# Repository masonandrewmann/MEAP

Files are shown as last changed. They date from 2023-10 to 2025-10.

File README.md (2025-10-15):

# Mason's ESP32 Audio Prototyping System

MEAP is a hardware and software environment for developing live computer music systems and rapidly prototyping digital electronic instruments.

MEAP's audio library is built as an expansion on top of [Mozzi](https://sensorium.github.io/Mozzi/), implementing extra features that take advantage of the computational power of the ESP32-S3 and improve/simplify the composer's experience.

[Documentation](https://masonmann.online/electronics/meap)

MEAP is used in [MPATE-GE 2047: Advanced Computer Music](https://masonmann.online/2047) at NYU

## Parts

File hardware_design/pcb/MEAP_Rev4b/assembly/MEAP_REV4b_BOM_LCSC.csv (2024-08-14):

Designator | Comment | Footprint | LCSC
U11 | TLV1117-50 | Package_TO_SOT_SMD:SOT-223-3_TabPin2 | ***
U9 | PAM8302AAD | Package_SO:MSOP-8_3x3mm_P0.65mm | C113367
U8 | SGTL5000XNLA3 | Package_DFN_QFN:QFN-20-1EP_3x3mm_P0.4mm_EP1.65x1.65mm | C2651833
U7 | TLV75733PDRV | Package_SON:WSON-6-1EP_2x2mm_P0.65mm_EP1x1.6mm | C2868428
U6 | AP7313-18A-7 | Package_TO_SOT_SMD:SOT-23 | C460372
U5 | MCP6002-xSN | Package_SO:SOIC-8_3.9x4.9mm_P1.27mm | C7377
U3 | ESP32-S3-WROOM-1 | PCM_Espressif:ESP32-S3-WROOM-1U | C3013946
U1 | 4051 | Package_SO:SOIC-16_3.9x9.9mm_P1.27mm | C21379
R26,R27 | 1k | Resistor_SMD:R_0603_1608Metric_Pad0.98x0.95mm_HandSolder | C21190
R25,R29,R30 | 100 | Resistor_SMD:R_0603_1608Metric_Pad0.98x0.95mm_HandSolder | C22775
R21,R23,R24 | 2k2 | Resistor_SMD:R_0603_1608Metric_Pad0.98x0.95mm_HandSolder | C4190
R10,R15 | 220 | Resistor_SMD:R_0603_1608Metric_Pad0.98x0.95mm_HandSolder | C22962
R5,R17,R18,R19,R20,R22,R28 | 10k | Resistor_SMD:R_0603_1608Metric_Pad0.98x0.95mm_HandSolder | C25804
R3,R6,R7,R9,R11,R12,R13,R14 | 100k | Resistor_SMD:R_0603_1608Metric_Pad0.98x0.95mm_HandSolder | C25803
R2,R8 | 47 | Resistor_SMD:R_0603_1608Metric_Pad0.98x0.95mm_HandSolder | C23182
R1,R4 | 330 | Resistor_SMD:R_0603_1608Metric_Pad0.98x0.95mm_HandSolder | C23138
Q1 | DMG2301L | Package_TO_SOT_SMD:SOT-23 | C102619
FB3,FB4 | 120 | Inductor_SMD:L_0603_1608Metric | C2941525
FB2 | 600 | Inductor_SMD:L_0603_1608Metric | C2982094
FB1 | 120 | Inductor_SMD:L_0603_1608Metric | C2941525
D3 | 1N4148 | Diode_SMD:D_SOD-323 | C2128
C25,C27 | 220p | Capacitor_SMD:C_0603_1608Metric_Pad1.08x0.95mm_HandSolder | C1603
C22 | 10u | Capacitor_SMD:C_0603_1608Metric_Pad1.08x0.95mm_HandSolder | C99231
C20 | 22u | Capacitor_SMD:C_1210_3225Metric | C342660
C16 | 0.15uF | Capacitor_SMD:C_0603_1608Metric_Pad1.08x0.95mm_HandSolder | C501839
C15 | 220n | Capacitor_SMD:C_0603_1608Metric_Pad1.08x0.95mm_HandSolder | C335532
C9,C11,C13,C14,C17,C19,C23,C24 | 2u2 | Capacitor_SMD:C_0603_1608Metric_Pad1.08x0.95mm_HandSolder | C914769
C2,C3,C4,C5,C6,C7,C8,C10,C12,C21 | 100n | Capacitor_SMD:C_0603_1608Metric_Pad1.08x0.95mm_HandSolder | C497032
C1,C18,C26,C30 | 1u | Capacitor_SMD:C_0603_1608Metric_Pad1.08x0.95mm_HandSolder | C696843
J22 | USB_B_Micro | Connector_USB:USB_Micro-B_Molex-105017-0001 | C136000

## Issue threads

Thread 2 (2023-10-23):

FTDI Header

masonandrewmann, 2023-10-23:
FTDI Header is very loose. At very least it needs strain relief but another kind of header might be better, or just uncut 6-pin headers. For now hot glue as stain relief seems to be the best option.

Closed 2023-10-30.

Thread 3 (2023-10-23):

Volume knob

masonandrewmann, 2023-10-23:
Volume knobs are very susceptible to being bent. They seem to become very noisy when this occurs. Maybe use a different kind of knob in the future.

masonandrewmann, 2023-10-23:
Volume knob also doesn't control line output, need to redesign the circuit for this. It would maybe also be nice to have a switched jack

Closed 2023-10-30.

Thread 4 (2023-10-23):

Control Knobs

masonandrewmann, 2023-10-23:
Control knobs get bent in backpacks. Would love to mount them on the box itself.

Closed 2023-10-30.

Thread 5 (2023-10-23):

Layout

masonandrewmann, 2023-10-23:
Several things get in the way of each other on the board.
When touch breakout is plugged in, the cable gets in the way of volume knob and programming buttons

Closed 2023-10-30.

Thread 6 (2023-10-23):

Kludges

masonandrewmann, 2023-10-23:
IO 19 is currently MISO for sd card SPI bus (pin 31 on kicad footprint)

IO 35 is currently PT_DIN for PT8211 (pin 7 on kicad footprint)

^^need to swap these

Volume Knob is backwards

SD card pins should be removed.

Closed 2024-08-14.

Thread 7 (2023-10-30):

rev3 hardware planning list

masonandrewmann, 2023-10-30:
midi output
CV output
Clock in/out
capacitive touch on i2c breakout with interrupts?

When touch breakout is plugged in, the cable gets in the way of volume knob and programming buttons
Spacing on program buttons is awkward, want to find a way to have FTDI programmer place ESP32 into PGM mode
FTDI header is flexible. Hot glue is a quick fix but would love a better connector.
Would love to avoid FTDI programming altogether, look into how arduino does their programming chip

How useful are the DIP switches?

Control knobs bend, maybe mount them on enclosure

Volume knob is easily damaged. Either use a non-trim pot or mount it somewhere else

Volume knob doesn't control headphone output. Place it before line out amp. Maybe also add switched jack

Stereo output? Maybe use a stereo 3.5mm as output instead of quarter inch?

Protection over speaker? (speaker grill cloth)

Maybe place pots on second mux and always use it (frees up a pin)

masonandrewmann, 2023-11-17:
FOR PROGRAMMING:
 Option 1: ESP32-S3 seems to have usb input pins
 Option 2: Use normal ESP32-WROOM with USB-UART chip (CP2102N)

Closed 2024-08-14.

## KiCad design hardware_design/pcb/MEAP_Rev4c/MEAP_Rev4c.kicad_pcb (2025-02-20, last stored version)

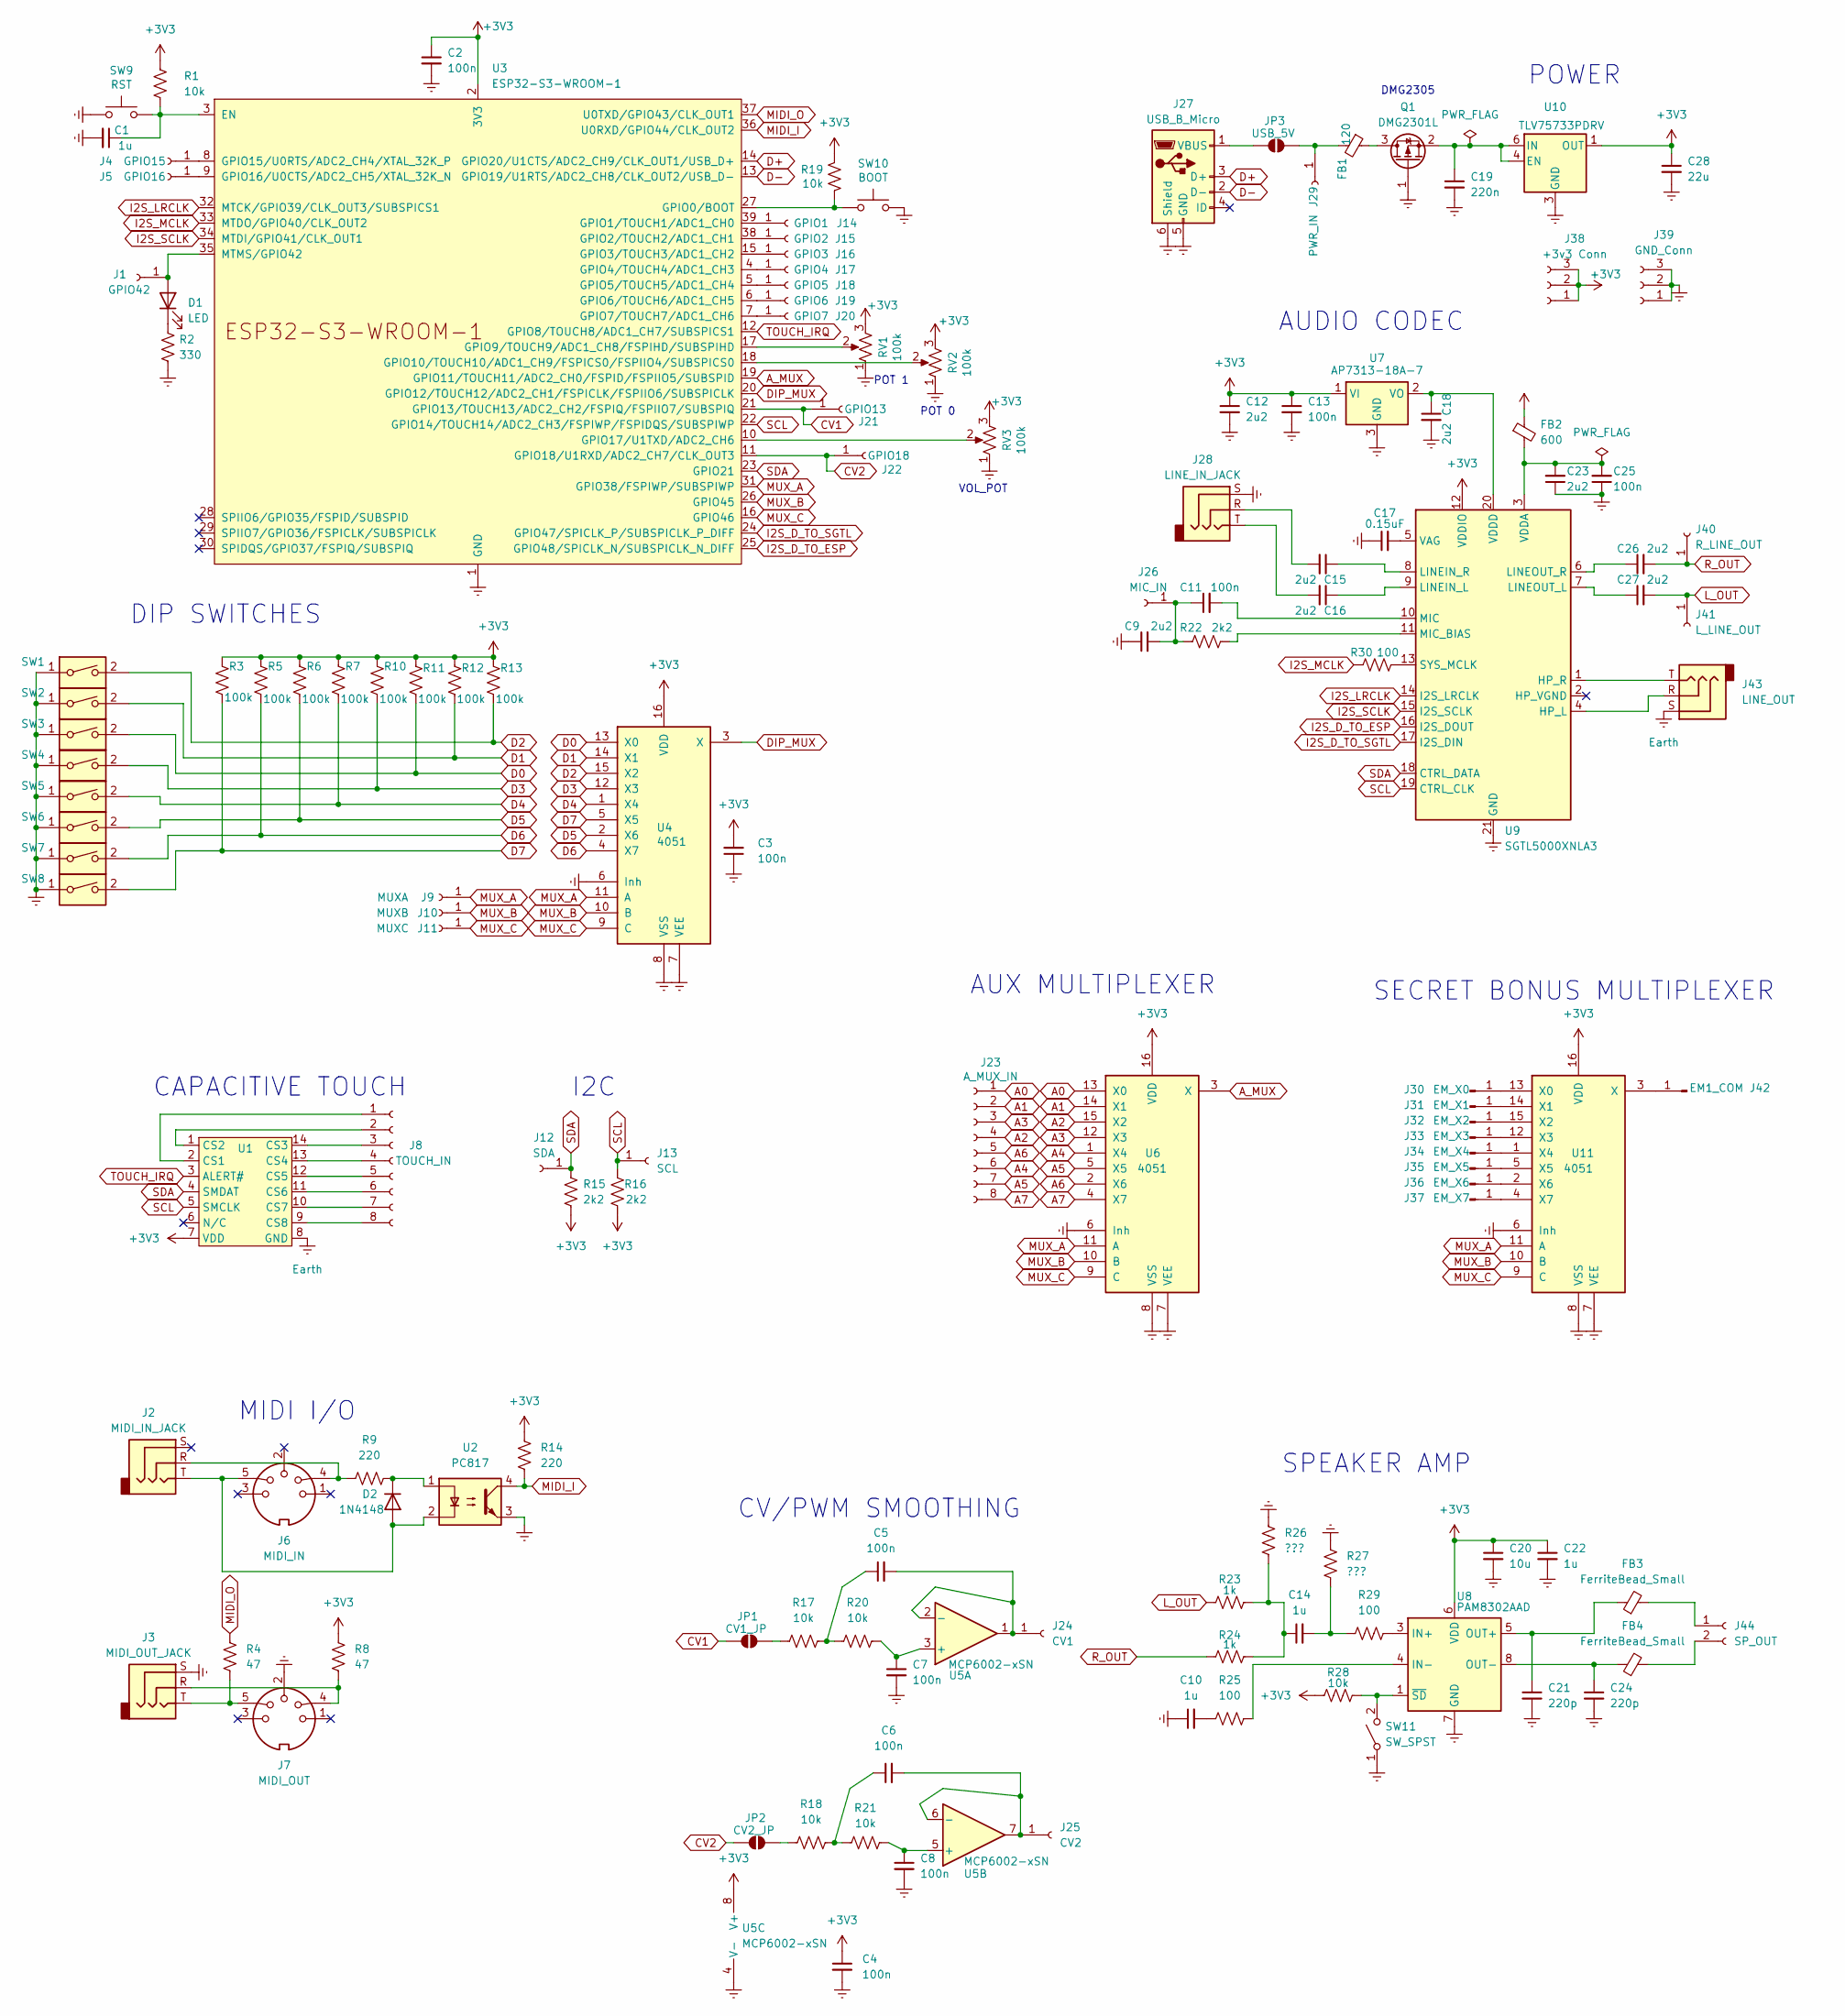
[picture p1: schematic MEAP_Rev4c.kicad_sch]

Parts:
C1, C10, C14, C22: 1u; C_0603_1608Metric_Pad1.08x0.95mm_HandSolder
C2, C3, C4, C5, C6, C7, C8, C11, C13, C25: 100n; C_0603_1608Metric_Pad1.08x0.95mm_HandSolder
C9, C12, C15, C16, C18, C23, C26, C27: 2u2; C_0603_1608Metric_Pad1.08x0.95mm_HandSolder
C17: 0.15uF; C_0603_1608Metric_Pad1.08x0.95mm_HandSolder
C19: 220n; C_0603_1608Metric_Pad1.08x0.95mm_HandSolder
C20: 10u; C_0603_1608Metric_Pad1.08x0.95mm_HandSolder
C21, C24: 220p; C_0603_1608Metric_Pad1.08x0.95mm_HandSolder
C28: 22u; C_1210_3225Metric
D1: LED; L_0805_2012Metric_Pad1.05x1.20mm_HandSolder
D2: 1N4148; D_SOD-323
FB1: 120; L_0603_1608Metric
FB2: 600; L_0603_1608Metric
FB3, FB4: FerriteBead_Small; L_0603_1608Metric
J1: GPIO42; Pin_D1.0mm_L10.0mm
J2: MIDI_IN_JACK; Jack_3.5mm_CUI_SJ1-3535NG_Horizontal_NO_FRONT
J3: MIDI_OUT_JACK; Jack_3.5mm_CUI_SJ1-3535NG_Horizontal_NO_FRONT
J4: GPIO15; Pin_D1.0mm_L10.0mm
J5: GPIO16; Pin_D1.0mm_L10.0mm
J6: MIDI_IN
J7: MIDI_OUT
J8: TOUCH_IN; PinHeader_2x04_P2.54mm_Vertical
J9: MUXA; Pin_D1.0mm_L10.0mm
J10: MUXB; Pin_D1.0mm_L10.0mm
J11: MUXC; Pin_D1.0mm_L10.0mm
J12: SDA; Pin_D1.0mm_L10.0mm
J13: SCL; Pin_D1.0mm_L10.0mm
J14: GPIO1; Pin_D1.0mm_L10.0mm
J15: GPIO2; Pin_D1.0mm_L10.0mm
J16: GPIO3; Pin_D1.0mm_L10.0mm
J17: GPIO4; Pin_D1.0mm_L10.0mm
J18: GPIO5; Pin_D1.0mm_L10.0mm
J19: GPIO6; Pin_D1.0mm_L10.0mm
J20: GPIO7; Pin_D1.0mm_L10.0mm
J21: GPIO13; Pin_D1.0mm_L10.0mm
J22: GPIO18; Pin_D1.0mm_L10.0mm
J23: A_MUX_IN; PinHeader_2x04_P2.54mm_Vertical
J24: CV1; Pin_D1.0mm_L10.0mm
J25: CV2; Pin_D1.0mm_L10.0mm
J26: MIC_IN; Pin_D1.0mm_L10.0mm
J27: USB_B_Micro; USB_Micro-B_Molex-105017-0001
J28: LINE_IN_JACK; Jack_3.5mm_CUI_SJ1-3535NG_Horizontal_NO_FRONT
J29: PWR_IN; Pin_D1.0mm_L10.0mm
J30: EM_X0; SolderWirePad_1x01_SMD_1x2mm
J31: EM_X1; SolderWirePad_1x01_SMD_1x2mm
J32: EM_X2; SolderWirePad_1x01_SMD_1x2mm
J33: EM_X3; SolderWirePad_1x01_SMD_1x2mm
J34: EM_X4; SolderWirePad_1x01_SMD_1x2mm
J35: EM_X5; SolderWirePad_1x01_SMD_1x2mm
J36: EM_X6; SolderWirePad_1x01_SMD_1x2mm
J37: EM_X7; SolderWirePad_1x01_SMD_1x2mm
J38: +3v3 Conn; PinHeader_1x03_P2.54mm_Vertical
J39: GND_Conn; PinHeader_1x03_P2.54mm_Vertical
J40: R_LINE_OUT; Pin_D1.0mm_L10.0mm
J41: L_LINE_OUT; Pin_D1.0mm_L10.0mm
J42: EM1_COM; SolderWirePad_1x01_SMD_1x2mm
J43: LINE_OUT; Jack_3.5mm_CUI_SJ1-3535NG_Horizontal_NO_FRONT
J44: SP_OUT; PinHeader_1x02_P2.54mm_Vertical
JP1: CV1_JP; SolderJumper-2_P1.3mm_Open_Pad1.0x1.5mm
JP2: CV2_JP; SolderJumper-2_P1.3mm_Open_Pad1.0x1.5mm
JP3: USB_5V; SolderJumper-2_P1.3mm_Open_Pad1.0x1.5mm
Q1: DMG2301L; SOT-23
R1, R17, R18, R19, R20, R21, R28: 10k; R_0603_1608Metric_Pad0.98x0.95mm_HandSolder
R2: 330; R_0603_1608Metric_Pad0.98x0.95mm_HandSolder
R3, R5, R6, R7, R10, R11, R12, R13: 100k; R_0603_1608Metric_Pad0.98x0.95mm_HandSolder
R4, R8: 47; R_0603_1608Metric_Pad0.98x0.95mm_HandSolder
R9, R14: 220; R_0603_1608Metric_Pad0.98x0.95mm_HandSolder
R15, R16, R22: 2k2; R_0603_1608Metric_Pad0.98x0.95mm_HandSolder
R23, R24: 1k; R_0603_1608Metric_Pad0.98x0.95mm_HandSolder
R25, R29, R30: 100; R_0603_1608Metric_Pad0.98x0.95mm_HandSolder
R26, R27: ???; R_0603_1608Metric_Pad0.98x0.95mm_HandSolder
RV1, RV2, RV3: 100k; PinHeader_1x03_P2.54mm_Vertical
SW1, SW2, SW3, SW4, SW5, SW6, SW7, SW8: SW_DIP_x01; SINGLE_DIP_SWITCH
SW9: RST; SW_Tactile_SPST_NO_Straight_CK_PTS636Sx25SMTRLFS
SW10: BOOT; SW_Tactile_SPST_NO_Straight_CK_PTS636Sx25SMTRLFS
SW11: SW_SPST; SW_Slide_SPDT_Straight_CK_OS102011MS2Q
U1: SOIC-14_3.9x8.7mm_P1.27mm
U2: PC817; DIP-4_W7.62mm
U3: ESP32-S3-WROOM-1; ESP32-S3-WROOM-1U
U4, U6, U11: 4051; SOIC-16_3.9x9.9mm_P1.27mm
U5: MCP6002-xSN; SOIC-8_3.9x4.9mm_P1.27mm
U7: AP7313-18A-7; SOT-23
U8: PAM8302AAD; MSOP-8_3x3mm_P0.65mm
U9: SGTL5000XNLA3; QFN-20-1EP_3x3mm_P0.4mm_EP1.65x1.65mm
U10: TLV75733PDRV; WSON-6-1EP_2x2mm_P0.65mm_EP1x1.6mm

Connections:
+3V3: C2.1, C3.2, C4.1, C12.1, C13.1, C20.1, C22.1, C28.1, FB2.1, J38.1, J38.2, J38.3, R1.1, R3.1, R5.1, R6.1, R7.1, R8.1, R10.1, R11.1, R12.1, R13.1, R14.1, R15.2, R16.2, R19.1, R28.1, RV1.3, RV2.3, RV3.3, U1.7 (VDD), U3.2 (3V3), U4.16 (VDD), U5.8 (V+), U6.16 (VDD), U7.1 (VI), U8.6 (VDD), U9.12 (VDDIO), U10.1 (OUT), U11.16 (VDD)
A0: J23.1, U6.13 (X0)
A1: J23.2, U6.14 (X1)
A2: J23.4, U6.15 (X2)
A3: J23.3, U6.12 (X3)
A4: J23.6, U6.1 (X4)
A5: J23.7, U6.5 (X5)
A6: J23.5, U6.2 (X6)
A7: J23.8, U6.4 (X7)
A_MUX: U3.19 (GPIO11/TOUCH11/ADC2_CH0/FSPID/FSPIIO5/S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), U6.3 (X)
CV1: J21.1, JP1.2 (B), U3.21 (GPIO13/TOUCH13/ADC2_CH2/FSPIQ/FSPIIO7/S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)
CV2: J22.1, JP2.2 (B), U3.11 (GPIO18/U1RXD/ADC2_CH7/CLK_OUT3)
D0: R11.2, SW3.2, U4.13 (X0)
D1: R12.2, SW2.2, U4.14 (X1)
D2: R13.2, SW1.2, U4.15 (X2)
D3: R10.2, SW4.2, U4.12 (X3)
D4: R7.2, SW5.2, U4.1 (X4)
D5: R6.2, SW6.2, U4.2 (X6)
D6: R5.2, SW7.2, U4.4 (X7)
D7: R3.2, SW8.2, U4.5 (X5)
D+: J27.3 (D+), U3.14 (GPIO20/U1CTS/ADC2_CH9/CLK_OUT1/USB_D+)
D-: J27.2 (D-), U3.13 (GPIO19/U1RTS/ADC2_CH8/CLK_OUT2/USB_D-)
DIP_MUX: U3.20 (GPIO12/TOUCH12/ADC2_CH1/FSPICLK/FSPIIO6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), U4.3 (X)
Earth: C1.2, C2.2, C3.1, C4.2, C7.2, C8.2, C9.1, C10.1, C12.2, C13.2, C17.1, C18.2, C19.2, C20.2, C21.2, C22.2, C23.1, C24.2, C25.1, C28.2, J3.S, J7.2, J27.5 (GND), J27.6 (Shield), J28.S, J39.1, J39.2, J39.3, J43.S, Q1.1 (G), R2.2, R26.2, R27.2, RV1.1, RV2.1, RV3.1, SW1.1, SW2.1, SW3.1, SW4.1, SW5.1, SW6.1, SW7.1, SW8.1, SW9.1, SW10.2, SW11.1 (A), U1.8 (GND), U2.3, U3.1 (GND), U3.40 (GND), U3.41 (GND), U4.6 (Inh), U4.7 (VEE), U4.8 (VSS), U5.4 (V-), U6.6 (Inh), U6.7 (VEE), U6.8 (VSS), U7.3 (GND), U8.7 (GND), U9.21 (GND), U10.3 (GND), U10.7 (GND), U11.6 (Inh), U11.7 (VEE), U11.8 (VSS)
I2S_D_TO_ESP: U3.25 (GPIO48/SPICLK_N/SUBSPICLK_N_DIFF), U9.16 (I2S_DOUT)
I2S_D_TO_SGTL: U3.24 (GPIO47/SPICLK_P/SUBSPICLK_P_DIFF), U9.17 (I2S_DIN)
I2S_LRCLK: U3.32 (MTCK/GPIO39/CLK_OUT3/SUBSPICS1), U9.14 (I2S_LRCLK)
I2S_MCLK: R30.1, U3.33 (MTDO/GPIO40/CLK_OUT2)
I2S_SCLK: U3.34 (MTDI/GPIO41/CLK_OUT1), U9.15 (I2S_SCLK)
L_OUT: C27.2, J41.1, R23.1
MIDI_I: R14.2, U2.4, U3.36 (U0RXD/GPIO44/CLK_OUT2)
MIDI_O: R4.1, U3.37 (U0TXD/GPIO43/CLK_OUT1)
MUX_A: J9.1, U3.31 (GPIO38/FSPIWP/SUBSPIWP), U4.11 (A), U6.11 (A), U11.11 (A)
MUX_B: J10.1, U3.26 (GPIO45), U4.10 (B), U6.10 (B), U11.10 (B)
MUX_C: J11.1, U3.16 (GPIO46), U4.9 (C), U6.9 (C), U11.9 (C)
unnamed: C5.1, R17.2, R20.1
unnamed: C6.1, R18.2, R21.1
unnamed: C10.2, R25.1
unnamed: C14.1, R23.2, R24.2, R26.1
unnamed: C14.2, R27.1, R29.1
unnamed: C15.2, J28.R
unnamed: C16.2, J28.T
unnamed: D1.2 (A), J1.1, U3.35 (MTMS/GPIO42)
unnamed: D1.1 (K), R2.1
unnamed: D2.2 (A), J2.T, J6.5, U2.2
unnamed: D2.1 (K), R9.2, U2.1
unnamed: J2.R, J6.4, R9.1
unnamed: J3.R, J7.4, R8.2
unnamed: J3.T, J7.5, R4.2
unnamed: J4.1, U3.8 (GPIO15/U0RTS/ADC2_CH4/XTAL_32K_P)
unnamed: J5.1, U3.9 (GPIO16/U0CTS/ADC2_CH5/XTAL_32K_N)
unnamed: J8.1, U1.2 (CS1)
unnamed: J8.2, U1.1 (CS2)
unnamed: J8.3, U1.14 (CS3)
unnamed: J8.4, U1.13 (CS4)
unnamed: J8.5, U1.12 (CS5)
unnamed: J8.6, U1.11 (CS6)
unnamed: J8.7, U1.10 (CS7)
unnamed: J8.8, U1.9 (CS8)
unnamed: J14.1, U3.39 (GPIO1/TOUCH1/ADC1_CH0)
unnamed: J15.1, U3.38 (GPIO2/TOUCH2/ADC1_CH1)
unnamed: J16.1, U3.15 (GPIO3/TOUCH3/ADC1_CH2)
unnamed: J17.1, U3.4 (GPIO4/TOUCH4/ADC1_CH3)
unnamed: J18.1, U3.5 (GPIO5/TOUCH5/ADC1_CH4)
unnamed: J19.1, U3.6 (GPIO6/TOUCH6/ADC1_CH5)
unnamed: J20.1, U3.7 (GPIO7/TOUCH7/ADC1_CH6)
unnamed: C5.2, J24.1, U5.1, U5.2 (-)
unnamed: C6.2, J25.1, U5.6 (-), U5.7
unnamed: C9.2, C11.1, J26.1, R22.1
unnamed: J27.1 (VBUS), JP3.2 (B)
unnamed: FB1.2, J29.1, JP3.1 (A)
unnamed: J30.1, U11.13 (X0)
unnamed: J31.1, U11.14 (X1)
unnamed: J32.1, U11.15 (X2)
unnamed: J33.1, U11.12 (X3)
unnamed: J34.1, U11.1 (X4)
unnamed: J35.1, U11.5 (X5)
unnamed: J36.1, U11.2 (X6)
unnamed: J37.1, U11.4 (X7)
unnamed: J42.1, U11.3 (X)
unnamed: FB3.2, J44.1
unnamed: FB4.2, J44.2
unnamed: JP1.1 (A), R17.1
unnamed: JP2.1 (A), R18.1
unnamed: FB1.1, Q1.3 (D)
unnamed: C19.1, Q1.2 (S), U10.4 (EN), U10.6 (IN)
unnamed: R28.2, SW11.2 (B), U8.1 (~SD)
unnamed: C1.1, R1.2, SW9.2, U3.3 (EN)
unnamed: R19.2, SW10.1, U3.27 (GPIO0/BOOT)
unnamed: RV1.2, U3.17 (GPIO9/TOUCH9/ADC1_CH8/FSPIHD/SUBSPIHD)
unnamed: RV2.2, U3.18 (GPIO10/TOUCH10/ADC1_CH9/FSPICS0/FSPIIO4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)
unnamed: RV3.2, U3.10 (GPIO17/U1TXD/ADC2_CH6)
unnamed: C7.1, R20.2, U5.3 (+)
unnamed: C8.1, R21.2, U5.5 (+)
unnamed: C18.1, U7.2 (VO), U9.20 (VDDD)
unnamed: R29.2, U8.3 (IN+)
unnamed: R25.2, U8.4 (IN-)
unnamed: C21.1, FB3.1, U8.5 (OUT+)
unnamed: C24.1, FB4.1, U8.8 (OUT-)
unnamed: J43.R, U9.4 (HP_L)
unnamed: J43.T, U9.1 (HP_R)
unnamed: C16.1, U9.9 (LINEIN_L)
unnamed: C15.1, U9.8 (LINEIN_R)
unnamed: C27.1, U9.7 (LINEOUT_L)
unnamed: C26.1, U9.6 (LINEOUT_R)
unnamed: C11.2, U9.10 (MIC)
unnamed: R22.2, U9.11 (MIC_BIAS)
unnamed: R30.2, U9.13 (SYS_MCLK)
unnamed: C17.2, U9.5 (VAG)
unnamed: C23.2, C25.2, FB2.2, U9.3 (VDDA)
R_OUT: C26.2, J40.1, R24.1
SCL: J13.1, R16.1, U1.5 (SMCLK), U3.22 (GPIO14/TOUCH14/ADC2_CH3/FSPIWP/FSPIDQS/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), U9.19 (CTRL_CLK)
SDA: J12.1, R15.1, U1.4 (SMDAT), U3.23 (GPIO21), U9.18 (CTRL_DATA)
TOUCH_IRQ: U1.3 (ALERT#), U3.12 (GPIO8/TOUCH8/ADC1_CH7/SUBSPICS1)

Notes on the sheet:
CV/PWM SMOOTHING
POWER
VOL_POT
POT 0
AUX MULTIPLEXER
I2C
DMG2305
POT 1
SPEAKER AMP
DIP SWITCHES
MIDI I/O
SECRET BONUS MULTIPLEXER
CAPACITIVE TOUCH
AUDIO CODEC

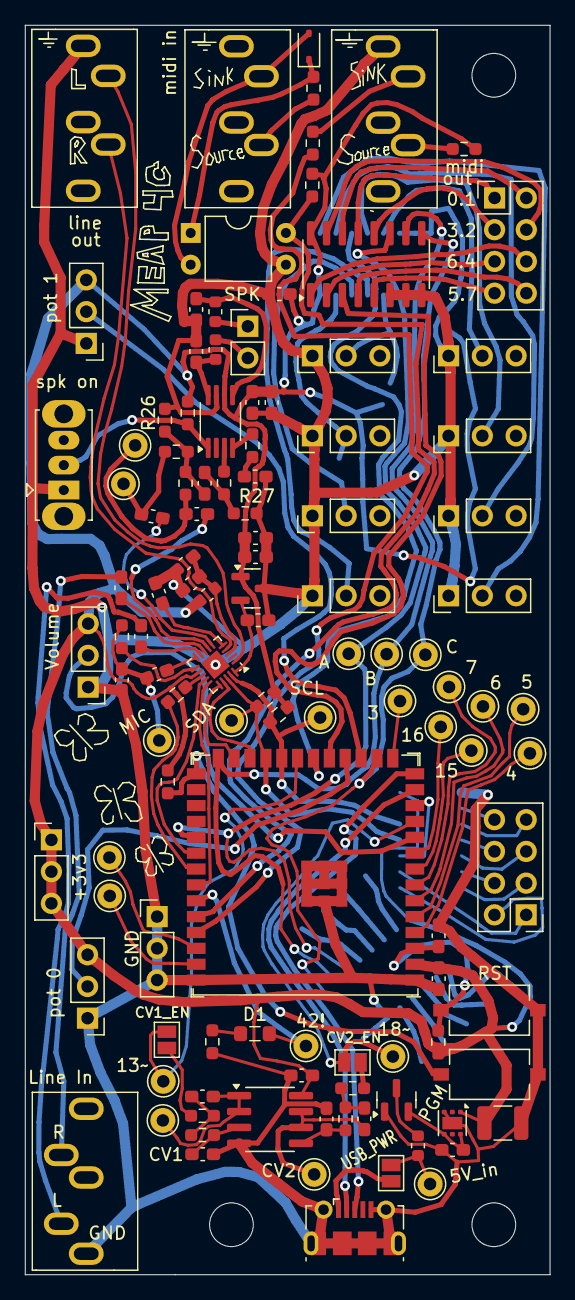
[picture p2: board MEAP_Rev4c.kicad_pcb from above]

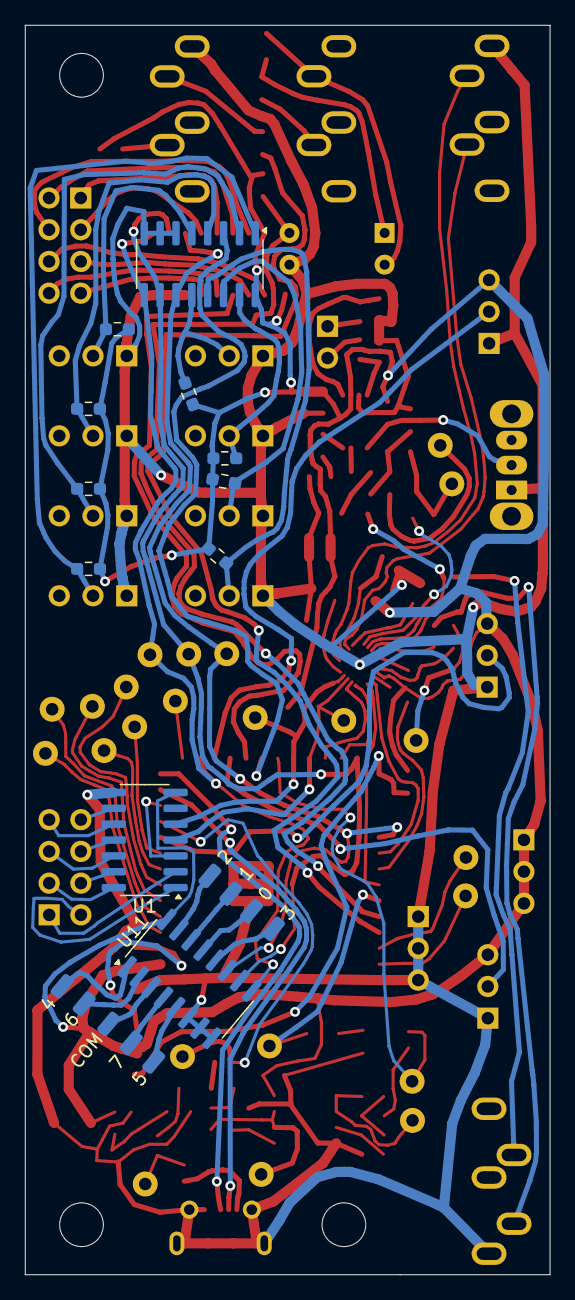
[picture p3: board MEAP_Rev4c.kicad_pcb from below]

Board: 2 copper layers, 42.0 x 100.0 mm, 135 parts (20 on the bottom side), 114 nets.

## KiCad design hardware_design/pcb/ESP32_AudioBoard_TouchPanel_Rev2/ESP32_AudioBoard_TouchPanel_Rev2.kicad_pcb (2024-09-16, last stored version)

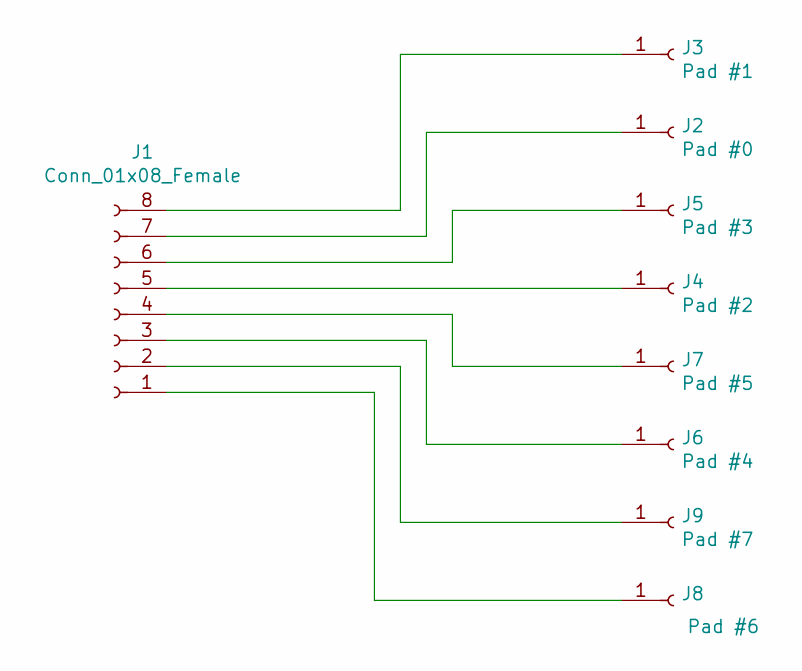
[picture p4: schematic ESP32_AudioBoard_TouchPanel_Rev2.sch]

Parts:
J1: Conn_01x08_Female; PinHeader_2x04_P2.54mm_Vertical
J2: Pad #0; TouchPad
J3: Pad #1; TouchPad
J4: Pad #2; TouchPad
J5: Pad #3; TouchPad
J6: Pad #4; TouchPad
J7: Pad #5; TouchPad
J8: Pad #6; TouchPad
J9: Pad #7; TouchPad

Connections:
unnamed: J1.1, J8.1
unnamed: J1.2, J9.1
unnamed: J1.3, J6.1
unnamed: J1.4, J7.1
unnamed: J1.5, J4.1
unnamed: J1.6, J5.1
unnamed: J1.7, J2.1
unnamed: J1.8, J3.1

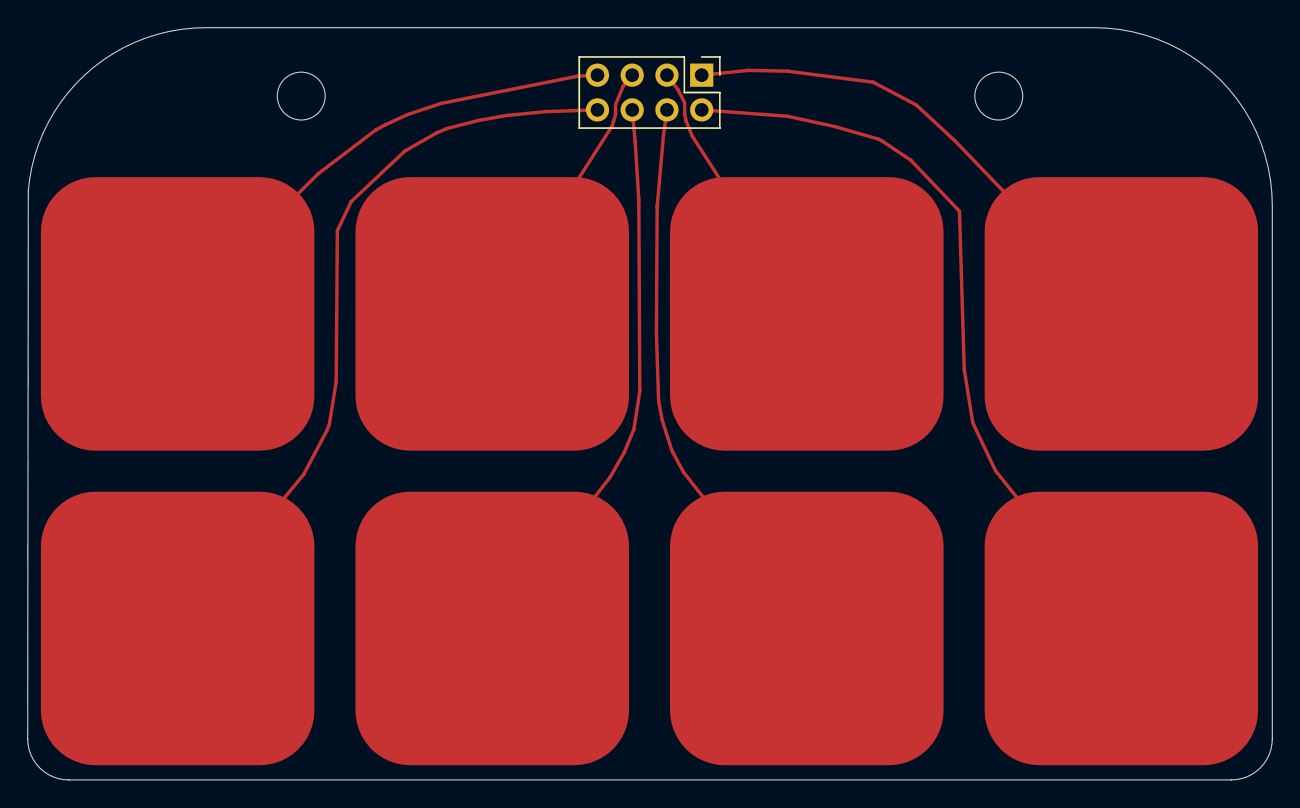
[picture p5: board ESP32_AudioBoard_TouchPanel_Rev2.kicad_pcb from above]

Board: 2 copper layers, 91.0 x 55.0 mm, 9 parts (0 on the bottom side), 8 nets.

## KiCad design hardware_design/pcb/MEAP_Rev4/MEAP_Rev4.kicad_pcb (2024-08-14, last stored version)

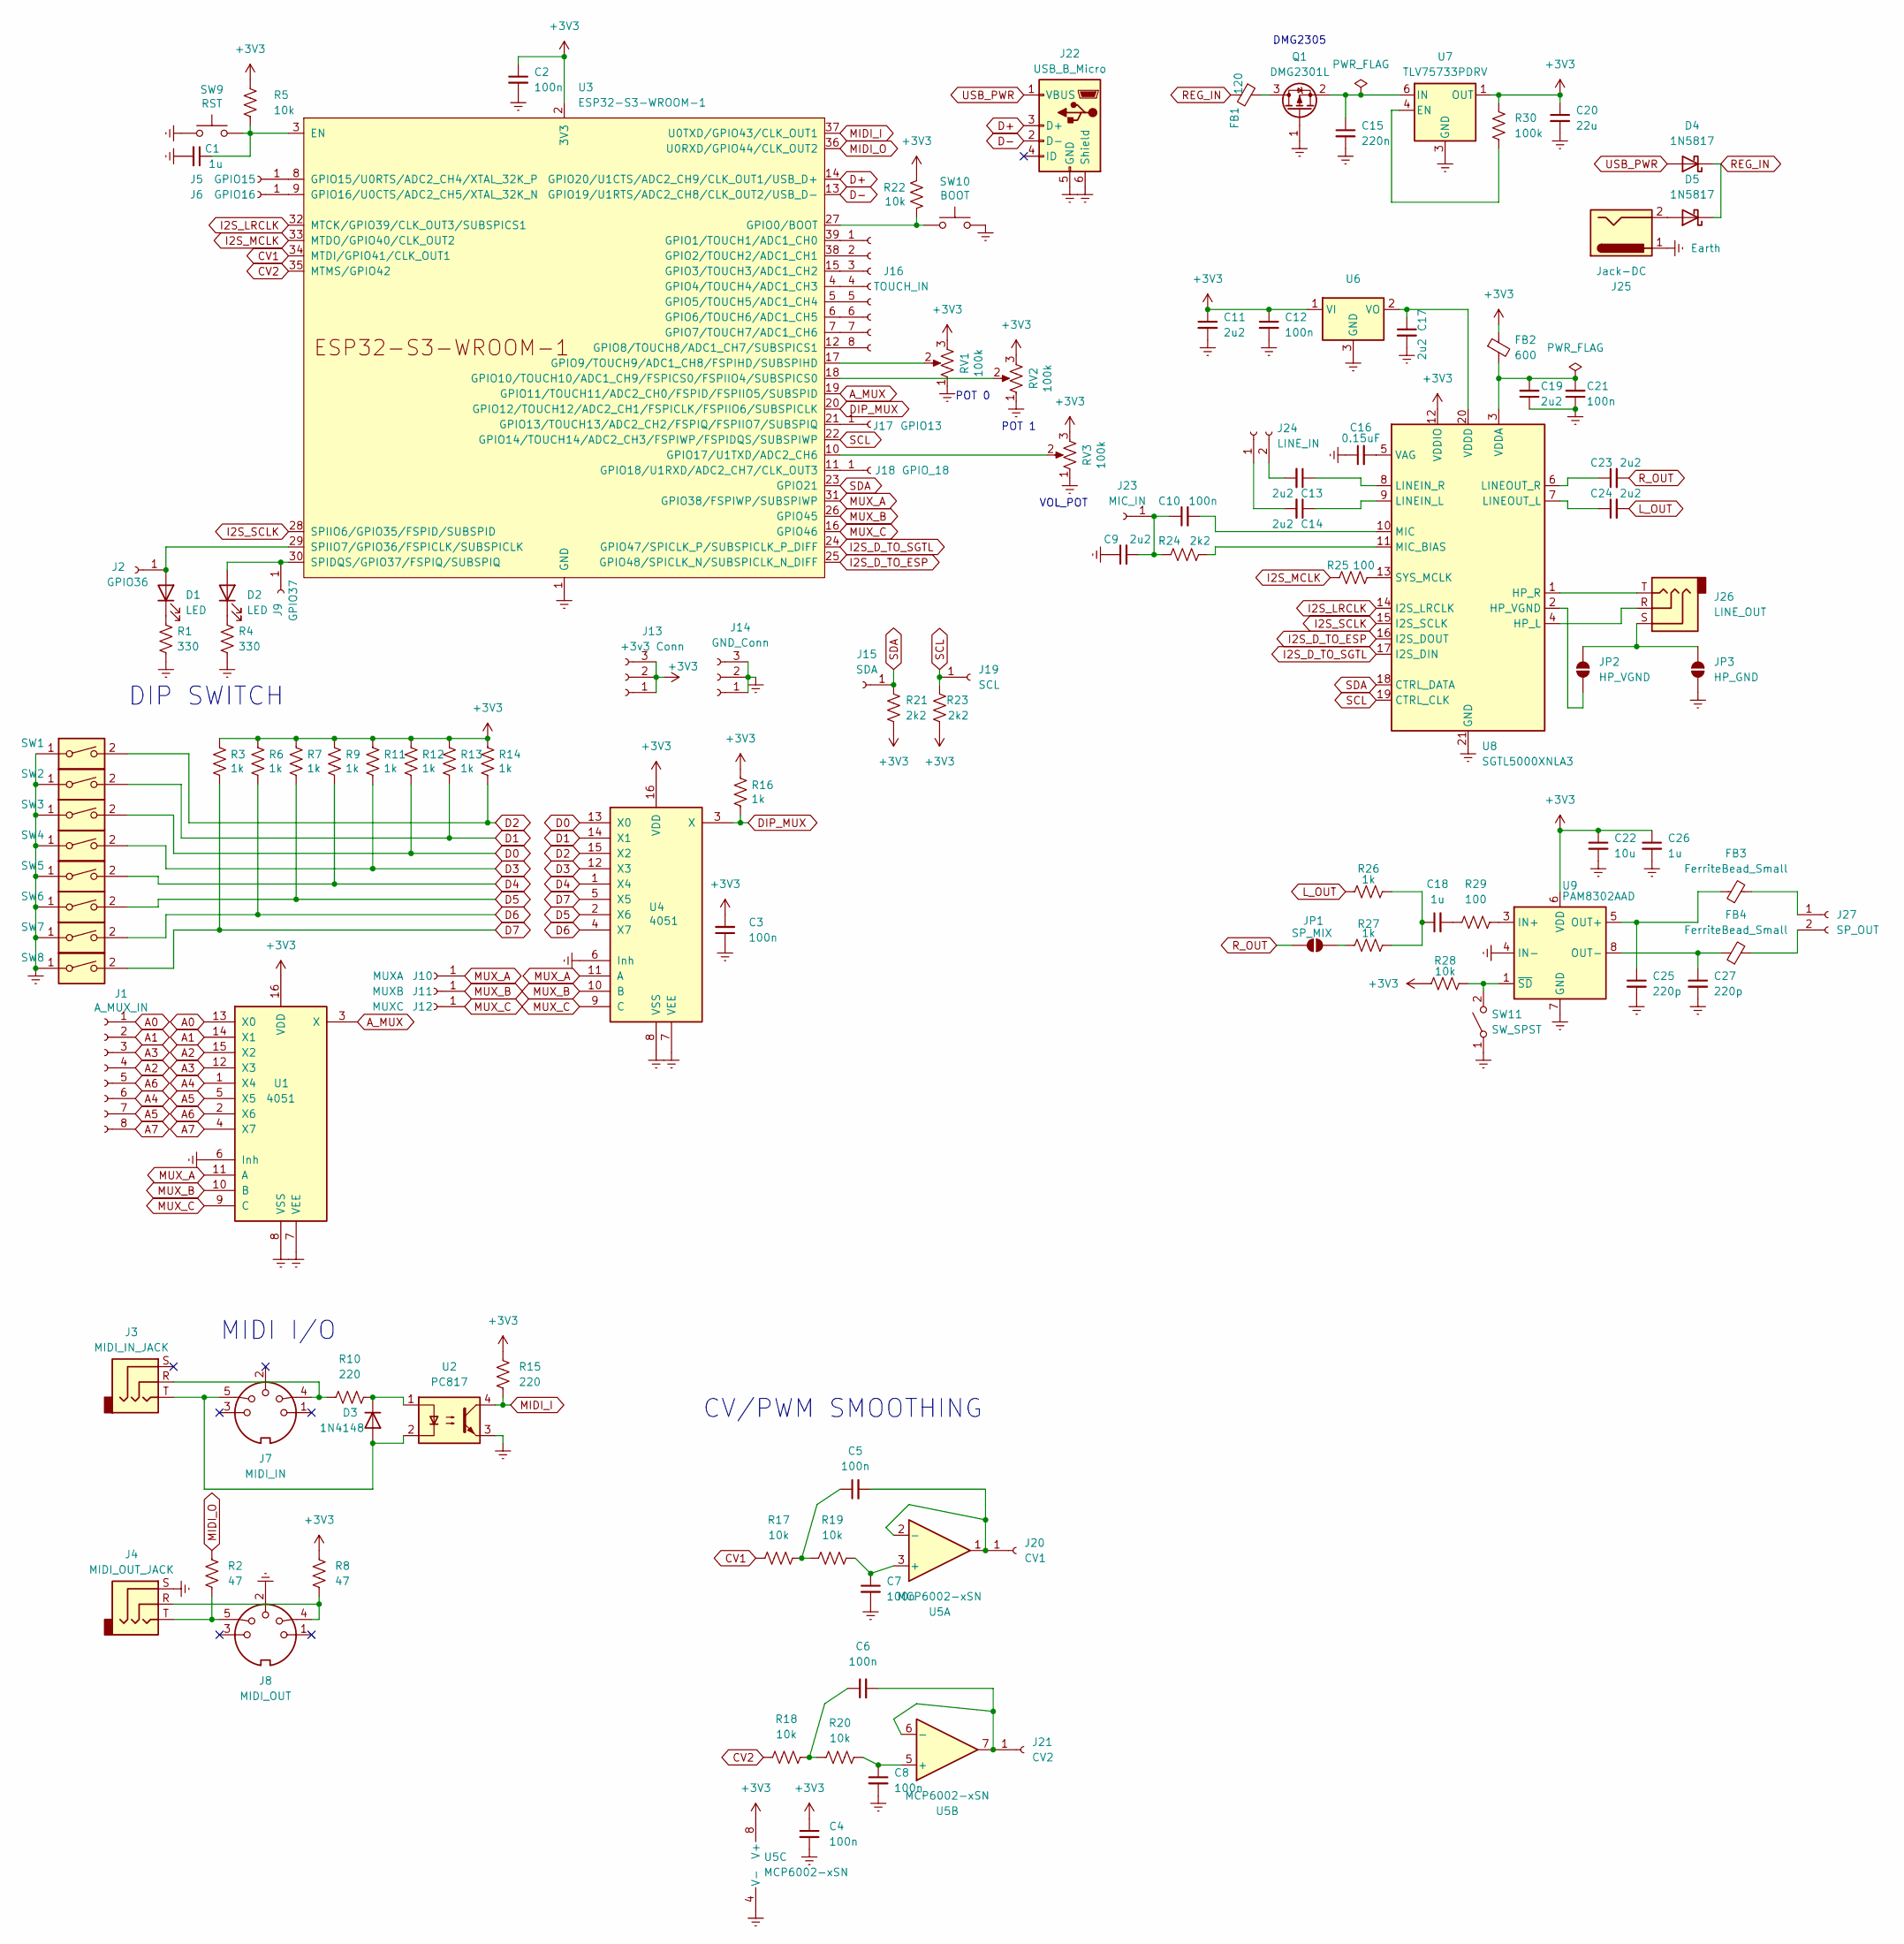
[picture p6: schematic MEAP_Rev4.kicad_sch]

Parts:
C1, C18, C26: 1u; C_0603_1608Metric_Pad1.08x0.95mm_HandSolder
C2, C3, C4, C5, C6, C7, C8, C10, C12, C21: 100n; C_0603_1608Metric_Pad1.08x0.95mm_HandSolder
C9, C11, C13, C14, C17, C19, C23, C24: 2u2; C_0603_1608Metric_Pad1.08x0.95mm_HandSolder
C15: 220n; C_0603_1608Metric_Pad1.08x0.95mm_HandSolder
C16: 0.15uF; C_0603_1608Metric_Pad1.08x0.95mm_HandSolder
C20: 22u; C_1210_3225Metric
C22: 10u; C_0603_1608Metric_Pad1.08x0.95mm_HandSolder
C25, C27: 220p; C_0603_1608Metric_Pad1.08x0.95mm_HandSolder
D1, D2: LED; LED_D3.0mm_Clear
D3: 1N4148; D_SOD-323
D4, D5: 1N5817; D_DO-41_SOD81_P2.54mm_Vertical_KathodeUp
FB1: 120; L_0603_1608Metric
FB2: 600; L_0603_1608Metric
FB3, FB4: FerriteBead_Small; L_0603_1608Metric
J1: A_MUX_IN; PinHeader_2x04_P2.54mm_Vertical
J2: GPIO36; Pin_D1.0mm_L10.0mm
J3: MIDI_IN_JACK; Jack_3.5mm_CUI_SJ1-3535NG_Horizontal_NO_FRONT
J4: MIDI_OUT_JACK; Jack_3.5mm_CUI_SJ1-3535NG_Horizontal_NO_FRONT
J5: GPIO15; Pin_D1.0mm_L10.0mm
J6: GPIO16; Pin_D1.0mm_L10.0mm
J7: MIDI_IN
J8: MIDI_OUT
J9: GPIO37; Pin_D1.0mm_L10.0mm
J10: MUXA; Pin_D1.0mm_L10.0mm
J11: MUXB; Pin_D1.0mm_L10.0mm
J12: MUXC; Pin_D1.0mm_L10.0mm
J13: +3v3 Conn; PinHeader_1x03_P2.54mm_Vertical
J14: GND_Conn; PinHeader_1x03_P2.54mm_Vertical
J15: SDA; Pin_D1.0mm_L10.0mm
J16: TOUCH_IN; PinHeader_2x04_P2.54mm_Vertical
J17: GPIO13; Pin_D1.0mm_L10.0mm
J18: GPIO_18; Pin_D1.0mm_L10.0mm
J19: SCL; Pin_D1.0mm_L10.0mm
J20: CV1; Pin_D1.0mm_L10.0mm
J21: CV2; Pin_D1.0mm_L10.0mm
J22: USB_B_Micro; USB_Micro-B_Molex-105017-0001
J23: MIC_IN; Pin_D1.0mm_L10.0mm
J24: LINE_IN; PinHeader_1x02_P2.54mm_Vertical
J25: Jack-DC; BarrelJack_Horizontal
J26: LINE_OUT; Jack_3.5mm_CUI_SJ1-3535NG_Horizontal_NO_FRONT
J27: SP_OUT; PinHeader_1x02_P2.54mm_Vertical
JP1: SP_MIX; SolderJumper-2_P1.3mm_Open_Pad1.0x1.5mm
JP2: HP_VGND; SolderJumper-2_P1.3mm_Open_RoundedPad1.0x1.5mm
JP3: HP_GND; SolderJumper-2_P1.3mm_Open_RoundedPad1.0x1.5mm
Q1: DMG2301L; SOT-23
R1, R4: 330; R_0603_1608Metric_Pad0.98x0.95mm_HandSolder
R2, R8: 47; R_0603_1608Metric_Pad0.98x0.95mm_HandSolder
R3, R6, R7, R9, R11, R12, R13, R14, R16, R26, R27: 1k; R_0603_1608Metric_Pad0.98x0.95mm_HandSolder
R5, R17, R18, R19, R20, R22, R28: 10k; R_0603_1608Metric_Pad0.98x0.95mm_HandSolder
R10, R15: 220; R_0603_1608Metric_Pad0.98x0.95mm_HandSolder
R21, R23, R24: 2k2; R_0603_1608Metric_Pad0.98x0.95mm_HandSolder
R25, R29: 100; R_0603_1608Metric_Pad0.98x0.95mm_HandSolder
R30: 100k; R_0603_1608Metric_Pad0.98x0.95mm_HandSolder
RV1, RV2, RV3: 100k; PinHeader_1x03_P2.54mm_Vertical
SW1, SW2, SW3, SW4, SW5, SW6, SW7, SW8: SW_DIP_x01; SINGLE_DIP_SWITCH
SW9: RST; SW_Tactile_SPST_NO_Straight_CK_PTS636Sx25SMTRLFS
SW10: BOOT; SW_Tactile_SPST_NO_Straight_CK_PTS636Sx25SMTRLFS
SW11: SW_SPST; SW_Slide_SPDT_Straight_CK_OS102011MS2Q
U1, U4: 4051; SOIC-16_3.9x9.9mm_P1.27mm
U2: PC817; DIP-4_W7.62mm
U3: ESP32-S3-WROOM-1; ESP32-S3-WROOM-1U
U5: MCP6002-xSN; SOIC-8_3.9x4.9mm_P1.27mm
U6: SOT-23
U7: TLV75733PDRV; WSON-6-1EP_2x2mm_P0.65mm_EP1x1.6mm
U8: SGTL5000XNLA3; QFN-20-1EP_3x3mm_P0.4mm_EP1.65x1.65mm
U9: PAM8302AAD; MSOP-8_3x3mm_P0.65mm

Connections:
+3V3: C2.1, C3.2, C4.1, C11.1, C12.1, C20.1, C22.1, C26.1, FB2.1, J13.1, J13.2, J13.3, R3.1, R5.1, R6.1, R7.1, R8.1, R9.1, R11.1, R12.1, R13.1, R14.1, R15.1, R16.1, R21.2, R22.1, R23.2, R28.1, R30.1, RV1.3, RV2.3, RV3.3, U1.16 (VDD), U3.2 (3V3), U4.16 (VDD), U5.8 (V+), U6.1 (VI), U7.1 (OUT), U8.12 (VDDIO), U9.6 (VDD)
A0: J1.1, U1.13 (X0)
A1: J1.2, U1.14 (X1)
A2: J1.4, U1.15 (X2)
A3: J1.3, U1.12 (X3)
A4: J1.6, U1.1 (X4)
A5: J1.7, U1.5 (X5)
A6: J1.5, U1.2 (X6)
A7: J1.8, U1.4 (X7)
A_MUX: U1.3 (X), U3.19 (GPIO11/TOUCH11/ADC2_CH0/FSPID/FSPIIO5/S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)
CV1: R17.1, U3.34 (MTDI/GPIO41/CLK_OUT1)
CV2: R18.1, U3.35 (MTMS/GPIO42)
D0: R12.2, SW3.2, U4.13 (X0)
D1: R13.2, SW2.2, U4.14 (X1)
D2: R14.2, SW1.2, U4.15 (X2)
D3: R11.2, SW4.2, U4.12 (X3)
D4: R9.2, SW5.2, U4.1 (X4)
D5: R7.2, SW6.2, U4.2 (X6)
D6: R6.2, SW7.2, U4.4 (X7)
D7: R3.2, SW8.2, U4.5 (X5)
D+: J22.3 (D+), U3.14 (GPIO20/U1CTS/ADC2_CH9/CLK_OUT1/USB_D+)
D-: J22.2 (D-), U3.13 (GPIO19/U1RTS/ADC2_CH8/CLK_OUT2/USB_D-)
DIP_MUX: R16.2, U3.20 (GPIO12/TOUCH12/ADC2_CH1/FSPICLK/FSPIIO6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), U4.3 (X)
Earth: C1.2, C2.2, C3.1, C4.2, C7.2, C8.2, C9.1, C11.2, C12.2, C15.2, C16.1, C17.2, C19.1, C20.2, C21.1, C22.2, C25.2, C26.2, C27.2, J4.S, J8.2, J14.1, J14.2, J14.3, J22.5 (GND), J22.6 (Shield), J25.1, JP3.1 (A), Q1.1 (G), R1.2, R4.2, RV1.1, RV2.1, RV3.1, SW1.1, SW2.1, SW3.1, SW4.1, SW5.1, SW6.1, SW7.1, SW8.1, SW9.1, SW10.2, SW11.1 (A), U1.6 (Inh), U1.7 (VEE), U1.8 (VSS), U2.3, U3.1 (GND), U3.40 (GND), U3.41 (GND), U4.6 (Inh), U4.7 (VEE), U4.8 (VSS), U5.4 (V-), U6.3 (GND), U7.3 (GND), U7.7 (GND), U8.21 (GND), U9.4 (IN-), U9.7 (GND)
I2S_D_TO_ESP: U3.25 (GPIO48/SPICLK_N/SUBSPICLK_N_DIFF), U8.16 (I2S_DOUT)
I2S_D_TO_SGTL: U3.24 (GPIO47/SPICLK_P/SUBSPICLK_P_DIFF), U8.17 (I2S_DIN)
I2S_LRCLK: U3.32 (MTCK/GPIO39/CLK_OUT3/SUBSPICS1), U8.14 (I2S_LRCLK)
I2S_MCLK: R25.1, U3.33 (MTDO/GPIO40/CLK_OUT2)
I2S_SCLK: U3.28 (SPIIO6/GPIO35/FSPID/SUBSPID), U8.15 (I2S_SCLK)
L_OUT: C24.2, R26.1
MIDI_I: R15.2, U2.4, U3.37 (U0TXD/GPIO43/CLK_OUT1)
MIDI_O: R2.1, U3.36 (U0RXD/GPIO44/CLK_OUT2)
MUX_A: J10.1, U1.11 (A), U3.31 (GPIO38/FSPIWP/SUBSPIWP), U4.11 (A)
MUX_B: J11.1, U1.10 (B), U3.26 (GPIO45), U4.10 (B)
MUX_C: J12.1, U1.9 (C), U3.16 (GPIO46), U4.9 (C)
unnamed: C5.1, R17.2, R19.1
unnamed: C6.1, R18.2, R20.1
unnamed: C18.1, R26.2, R27.2
unnamed: C18.2, R29.1
unnamed: D1.2 (A), J2.1, U3.29 (SPIIO7/GPIO36/FSPICLK/SUBSPICLK)
unnamed: D1.1 (K), R1.1
unnamed: D2.2 (A), J9.1, U3.30 (SPIDQS/GPIO37/FSPIQ/SUBSPIQ)
unnamed: D2.1 (K), R4.1
unnamed: D3.2 (A), J3.T, J7.5, U2.2
unnamed: D3.1 (K), R10.2, U2.1
unnamed: D5.2 (A), J25.2
unnamed: J3.R, J7.4, R10.1
unnamed: J4.R, J8.4, R8.2
unnamed: J4.T, J8.5, R2.2
unnamed: J5.1, U3.8 (GPIO15/U0RTS/ADC2_CH4/XTAL_32K_P)
unnamed: J6.1, U3.9 (GPIO16/U0CTS/ADC2_CH5/XTAL_32K_N)
unnamed: J16.1, U3.39 (GPIO1/TOUCH1/ADC1_CH0)
unnamed: J16.2, U3.38 (GPIO2/TOUCH2/ADC1_CH1)
unnamed: J16.3, U3.15 (GPIO3/TOUCH3/ADC1_CH2)
unnamed: J16.4, U3.4 (GPIO4/TOUCH4/ADC1_CH3)
unnamed: J16.5, U3.5 (GPIO5/TOUCH5/ADC1_CH4)
unnamed: J16.6, U3.6 (GPIO6/TOUCH6/ADC1_CH5)
unnamed: J16.7, U3.7 (GPIO7/TOUCH7/ADC1_CH6)
unnamed: J16.8, U3.12 (GPIO8/TOUCH8/ADC1_CH7/SUBSPICS1)
unnamed: J17.1, U3.21 (GPIO13/TOUCH13/ADC2_CH2/FSPIQ/FSPIIO7/S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)
unnamed: J18.1, U3.11 (GPIO18/U1RXD/ADC2_CH7/CLK_OUT3)
unnamed: C5.2, J20.1, U5.1, U5.2 (-)
unnamed: C6.2, J21.1, U5.6 (-), U5.7
unnamed: C9.2, C10.1, J23.1, R24.1
unnamed: C14.2, J24.1
unnamed: C13.2, J24.2
unnamed: FB3.2, J27.1
unnamed: FB4.2, J27.2
unnamed: JP1.1 (A), R27.1
unnamed: JP2.1 (A), U8.2 (HP_VGND)
unnamed: J26.S, JP2.2 (B), JP3.2 (B)
unnamed: FB1.1, Q1.3 (D)
unnamed: C15.1, Q1.2 (S), U7.6 (IN)
unnamed: R28.2, SW11.2 (B), U9.1 (~SD)
unnamed: C1.1, R5.2, SW9.2, U3.3 (EN)
unnamed: R22.2, SW10.1, U3.27 (GPIO0/BOOT)
unnamed: RV1.2, U3.17 (GPIO9/TOUCH9/ADC1_CH8/FSPIHD/SUBSPIHD)
unnamed: RV2.2, U3.18 (GPIO10/TOUCH10/ADC1_CH9/FSPICS0/FSPIIO4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)
unnamed: RV3.2, U3.10 (GPIO17/U1TXD/ADC2_CH6)
unnamed: C7.1, R19.2, U5.3 (+)
unnamed: C8.1, R20.2, U5.5 (+)
unnamed: C17.1, U6.2 (VO), U8.20 (VDDD)
unnamed: R30.2, U7.4 (EN)
unnamed: J26.R, U8.4 (HP_L)
unnamed: J26.T, U8.1 (HP_R)
unnamed: C14.1, U8.9 (LINEIN_L)
unnamed: C13.1, U8.8 (LINEIN_R)
unnamed: C24.1, U8.7 (LINEOUT_L)
unnamed: C23.1, U8.6 (LINEOUT_R)
unnamed: C10.2, U8.10 (MIC)
unnamed: R24.2, U8.11 (MIC_BIAS)
unnamed: R25.2, U8.13 (SYS_MCLK)
unnamed: C16.2, U8.5 (VAG)
unnamed: C19.2, C21.2, FB2.2, U8.3 (VDDA)
unnamed: R29.2, U9.3 (IN+)
unnamed: C25.1, FB3.1, U9.5 (OUT+)
unnamed: C27.1, FB4.1, U9.8 (OUT-)
REG_IN: D4.1 (K), D5.1 (K), FB1.2
R_OUT: C23.2, JP1.2 (B)
SCL: J19.1, R23.1, U3.22 (GPIO14/TOUCH14/ADC2_CH3/FSPIWP/FSPIDQS/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), U8.19 (CTRL_CLK)
SDA: J15.1, R21.1, U3.23 (GPIO21), U8.18 (CTRL_DATA)
USB_PWR: D4.2 (A), J22.1 (VBUS)

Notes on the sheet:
CV/PWM SMOOTHING
VOL_POT
POT 1
DMG2305
POT 0
DIP SWITCH
MIDI I/O

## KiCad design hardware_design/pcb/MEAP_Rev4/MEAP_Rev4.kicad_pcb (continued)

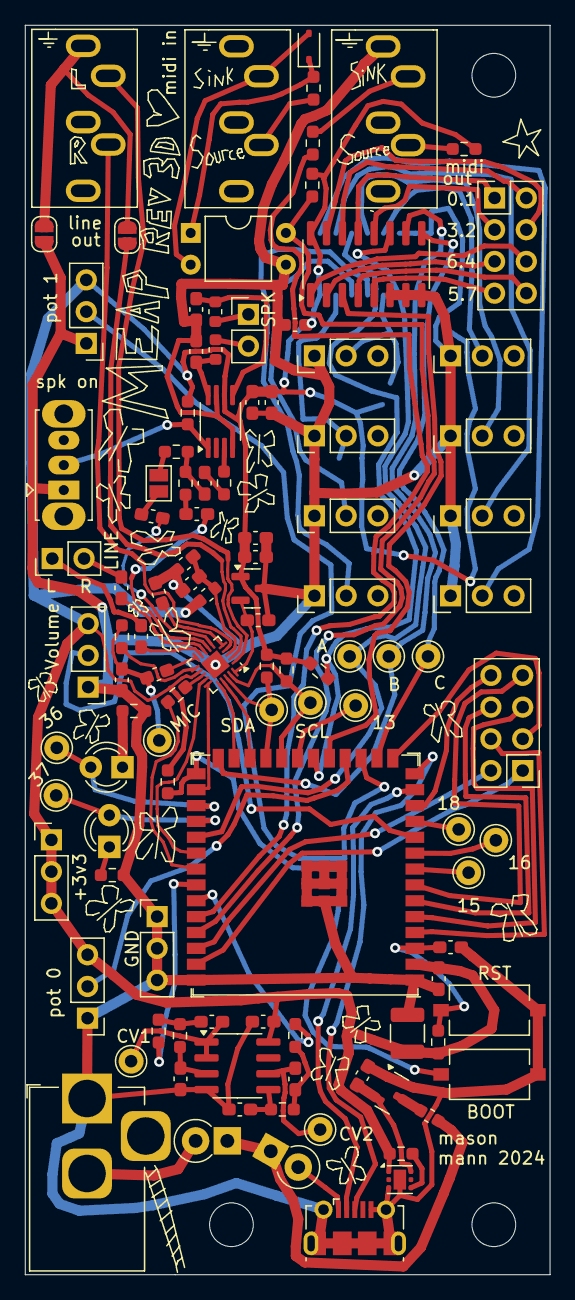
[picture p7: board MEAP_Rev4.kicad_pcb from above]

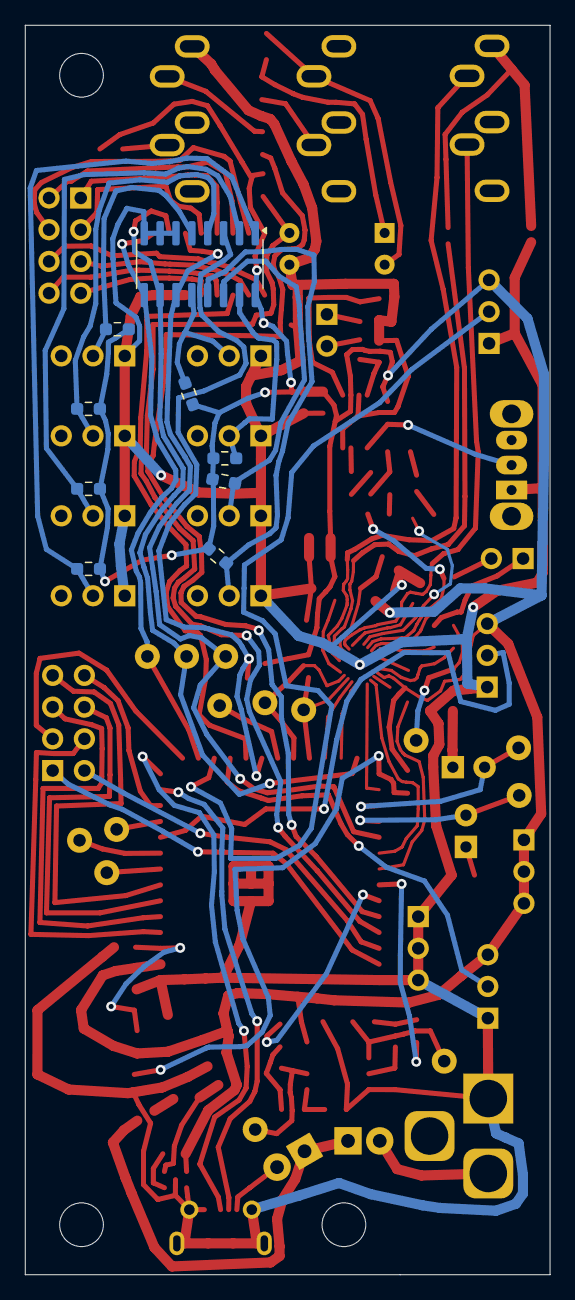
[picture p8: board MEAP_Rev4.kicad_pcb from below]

Board: 2 copper layers, 42.0 x 100.0 mm, 118 parts (9 on the bottom side), 102 nets.

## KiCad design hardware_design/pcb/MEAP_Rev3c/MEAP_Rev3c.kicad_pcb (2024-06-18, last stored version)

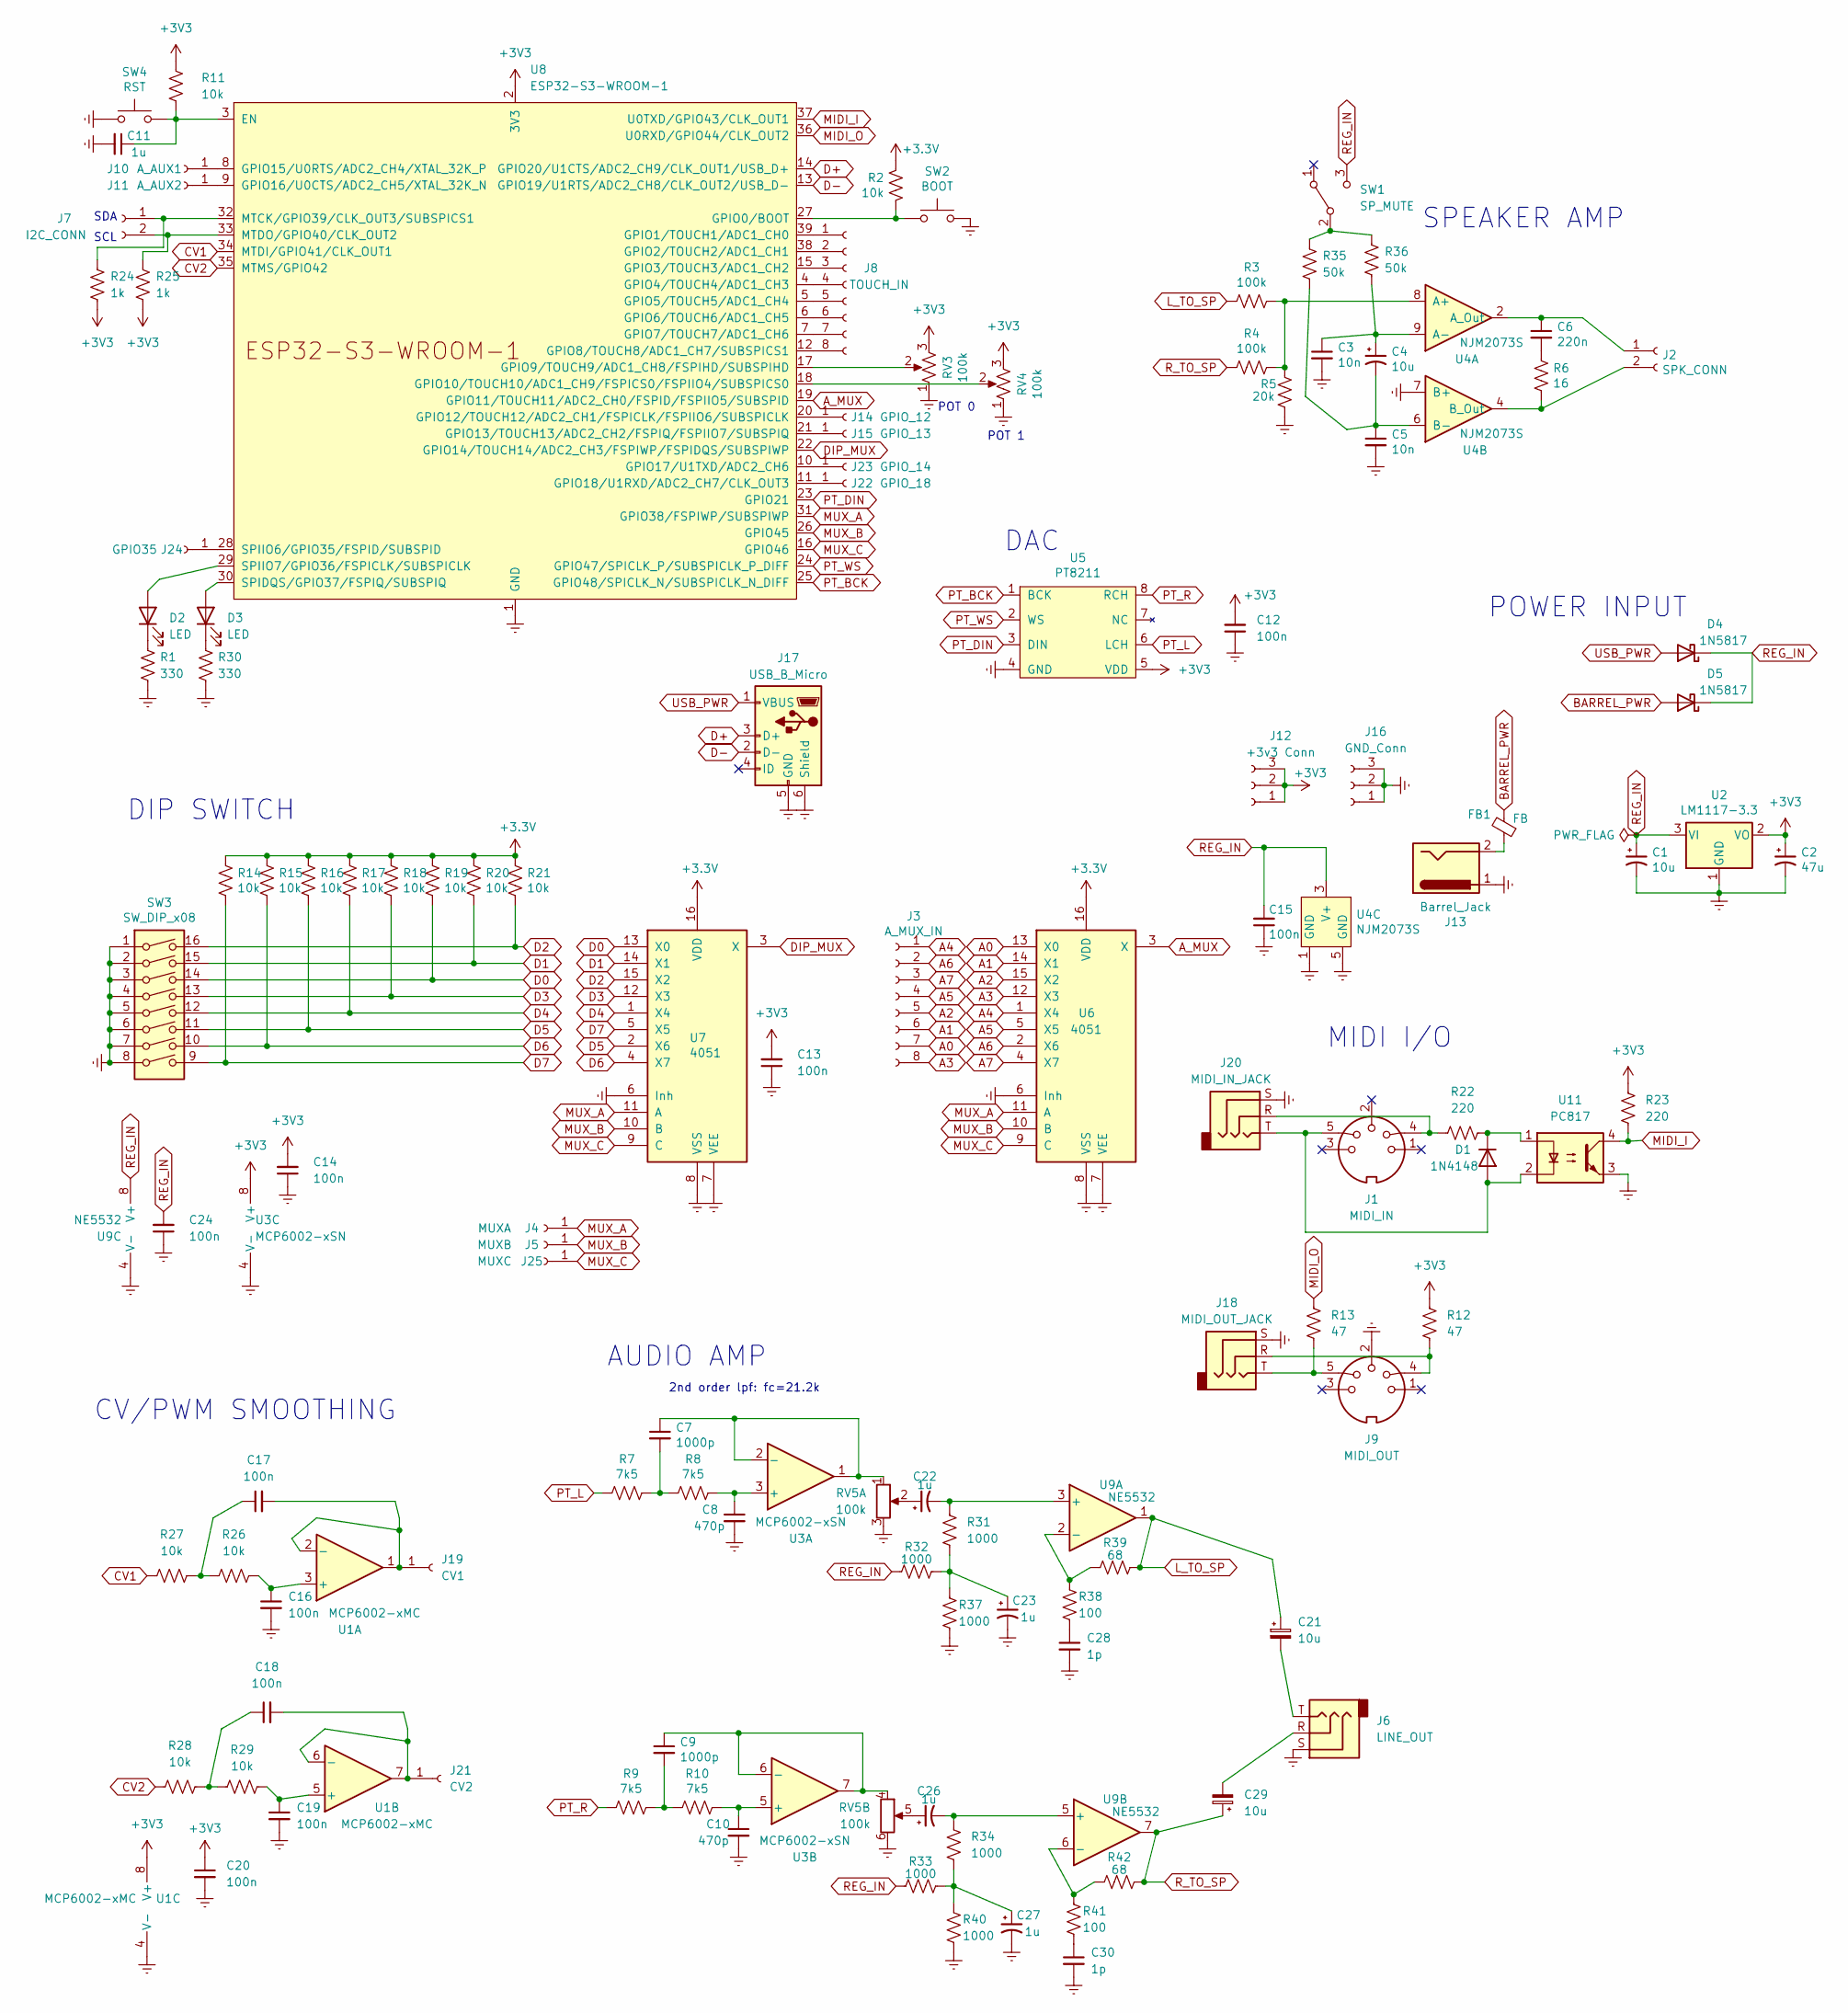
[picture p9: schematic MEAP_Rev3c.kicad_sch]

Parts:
C1, C4, C21, C29: 10u; C_0805_2012Metric_Pad1.18x1.45mm_HandSolder
C2: 47u; C_0805_2012Metric_Pad1.18x1.45mm_HandSolder
C3, C5: 10n; C_0603_1608Metric_Pad1.08x0.95mm_HandSolder
C6: 220n; C_0603_1608Metric_Pad1.08x0.95mm_HandSolder
C7, C9: 1000p; C_0603_1608Metric_Pad1.08x0.95mm_HandSolder
C8, C10: 470p; C_0603_1608Metric_Pad1.08x0.95mm_HandSolder
C11, C22, C23, C26, C27: 1u; C_0805_2012Metric_Pad1.18x1.45mm_HandSolder
C12, C13, C14, C15, C16, C17, C18, C19, C20, C24: 100n; C_0603_1608Metric_Pad1.08x0.95mm_HandSolder
C28, C30: 1p; C_0603_1608Metric_Pad1.08x0.95mm_HandSolder
D1: 1N4148; D_SOD-323
D2, D3: LED; LED_D3.0mm_Clear
D4, D5: 1N5817; D_DO-41_SOD81_P2.54mm_Vertical_AnodeUp
FB1: FB; L_0805_2012Metric_Pad1.15x1.40mm_HandSolder
J1: MIDI_IN
J2: SPK_CONN; PinHeader_1x02_P2.54mm_Vertical
J3: A_MUX_IN; PinHeader_2x04_P2.54mm_Vertical
J4: MUXA; Pin_D1.0mm_L10.0mm
J5: MUXB; Pin_D1.0mm_L10.0mm
J6: LINE_OUT; Jack_3.5mm_CUI_SJ1-3535NG_Horizontal_NO_FRONT
J7: I2C_CONN; PinHeader_1x02_P2.54mm_Vertical
J8: TOUCH_IN; PinHeader_2x04_P2.54mm_Vertical
J9: MIDI_OUT
J10: A_AUX1; Pin_D1.0mm_L10.0mm
J11: A_AUX2; Pin_D1.0mm_L10.0mm
J12: +3v3 Conn; PinHeader_1x03_P2.54mm_Vertical
J13: Barrel_Jack; BarrelJack_Horizontal
J14: GPIO_12; Pin_D1.0mm_L10.0mm
J15: GPIO_13; Pin_D1.0mm_L10.0mm
J16: GND_Conn; PinHeader_1x03_P2.54mm_Vertical
J17: USB_B_Micro; USB_Micro-B_Molex-105017-0001
J18: MIDI_OUT_JACK; Jack_3.5mm_CUI_SJ1-3535NG_Horizontal_NO_FRONT
J19: CV1; Pin_D1.0mm_L10.0mm
J20: MIDI_IN_JACK; Jack_3.5mm_CUI_SJ1-3535NG_Horizontal_NO_FRONT
J21: CV2; Pin_D1.0mm_L10.0mm
J22: GPIO_18; Pin_D1.0mm_L10.0mm
J23: GPIO_14; Pin_D1.0mm_L10.0mm
J24: GPIO35; Pin_D1.0mm_L10.0mm
J25: MUXC; Pin_D1.0mm_L10.0mm
R1, R30: 330; R_0603_1608Metric_Pad0.98x0.95mm_HandSolder
R2, R11, R14, R15, R16, R17, R18, R19, R20, R21, R26, R27, R28, R29: 10k; R_0603_1608Metric_Pad0.98x0.95mm_HandSolder
R3, R4: 100k; R_0603_1608Metric_Pad0.98x0.95mm_HandSolder
R5: 20k; R_0603_1608Metric_Pad0.98x0.95mm_HandSolder
R6: 16; R_0603_1608Metric_Pad0.98x0.95mm_HandSolder
R7, R8, R9, R10: 7k5; R_0603_1608Metric_Pad0.98x0.95mm_HandSolder
R12, R13: 47; R_0603_1608Metric_Pad0.98x0.95mm_HandSolder
R22, R23: 220; R_0603_1608Metric_Pad0.98x0.95mm_HandSolder
R24, R25: 1k; R_0603_1608Metric_Pad0.98x0.95mm_HandSolder
R31, R32, R33, R34, R37, R40: 1000; R_0603_1608Metric_Pad0.98x0.95mm_HandSolder
R35, R36: 50k; R_0603_1608Metric_Pad0.98x0.95mm_HandSolder
R38, R41: 100; R_0603_1608Metric_Pad0.98x0.95mm_HandSolder
R39, R42: 68; R_0603_1608Metric_Pad0.98x0.95mm_HandSolder
RV3, RV4: 100k; PinHeader_1x03_P2.54mm_Vertical
RV5: 100k; Dual_Green_Pot
SW1: SP_MUTE; PinHeader_1x03_P2.54mm_Vertical
SW2: BOOT; SW_Tactile_SPST_NO_Straight_CK_PTS636Sx25SMTRLFS
SW3: SW_DIP_x08; DIP-16_W7.62mm_Socket
SW4: RST; SW_Tactile_SPST_NO_Straight_CK_PTS636Sx25SMTRLFS
U1: MCP6002-xMC; SOIC-8_3.9x4.9mm_P1.27mm
U2: LM1117-3.3; SOT-223
U3: MCP6002-xSN; SOIC-8_3.9x4.9mm_P1.27mm
U4: NJM2073S; SIP-9_21.54x3mm_P2.54mm
U5: PT8211; SOIC-8_3.9x4.9mm_P1.27mm
U6, U7: 4051; SOIC-16_3.9x9.9mm_P1.27mm
U8: ESP32-S3-WROOM-1
U9: NE5532; SOIC-8_3.9x4.9mm_P1.27mm
U11: PC817; DIP-4_W7.62mm

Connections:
A0: J3.7, U6.13 (X0)
A1: J3.6, U6.14 (X1)
A2: J3.5, U6.15 (X2)
A3: J3.8, U6.12 (X3)
A4: J3.1, U6.1 (X4)
A5: J3.4, U6.5 (X5)
A6: J3.2, U6.2 (X6)
A7: J3.3, U6.4 (X7)
A_MUX: U6.3 (X), U8.19 (GPIO11/TOUCH11/ADC2_CH0/FSPID/FSPIIO5/S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)
BARREL_PWR: D5.2 (A), FB1.2
CV1: R27.1, U8.34 (MTDI/GPIO41/CLK_OUT1)
CV2: R28.1, U8.35 (MTMS/GPIO42)
D0: R19.2, SW3.14, U7.13 (X0)
D1: R20.2, SW3.15, U7.14 (X1)
D2: R21.2, SW3.16, U7.15 (X2)
D3: R18.2, SW3.13, U7.12 (X3)
D4: R17.2, SW3.12, U7.1 (X4)
D5: R16.2, SW3.11, U7.2 (X6)
D6: R15.2, SW3.10, U7.4 (X7)
D7: R14.2, SW3.9, U7.5 (X5)
D+: J17.3 (D+), U8.14 (GPIO20/U1CTS/ADC2_CH9/CLK_OUT1/USB_D+)
D-: J17.2 (D-), U8.13 (GPIO19/U1RTS/ADC2_CH8/CLK_OUT2/USB_D-)
DIP_MUX: U7.3 (X), U8.22 (GPIO14/TOUCH14/ADC2_CH3/FSPIWP/FSPIDQS/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)
Earth: C1.2, C2.2, C3.2, C5.2, C8.2, C10.2, C11.2, C12.1, C13.1, C14.1, C15.1, C16.2, C19.2, C20.2, C23.2, C24.1, C27.2, C28.2, C30.2, J6.S, J9.2, J13.1, J16.1, J16.2, J16.3, J17.5 (GND), J17.6 (Shield), J18.S, J20.S, R1.2, R5.1, R30.2, R37.2, R40.2, RV3.1, RV4.1, RV5.3, RV5.6, SW2.2, SW3.1, SW3.2, SW3.3, SW3.4, SW3.5, SW3.6, SW3.7, SW3.8, SW4.1, U1.4 (V-), U1.9 (V-), U2.1 (GND), U3.4 (V-), U4.1 (GND), U4.5 (GND), U4.7 (B+), U5.4 (GND), U6.6 (Inh), U6.7 (VEE), U6.8 (VSS), U7.6 (Inh), U7.7 (VEE), U7.8 (VSS), U8.1 (GND), U8.40 (GND), U8.41 (GND), U9.4 (V-), U11.3
L_TO_SP: C21.1, R3.2, R39.1, U9.1
MIDI_I: R23.2, U8.37 (U0TXD/GPIO43/CLK_OUT1), U11.4
MIDI_O: R13.1, U8.36 (U0RXD/GPIO44/CLK_OUT2)
MUX_A: J4.1, U6.11 (A), U7.11 (A), U8.31 (GPIO38/FSPIWP/SUBSPIWP)
MUX_B: J5.1, U6.10 (B), U7.10 (B), U8.26 (GPIO45)
MUX_C: J25.1, U6.9 (C), U7.9 (C), U8.16 (GPIO46)
unnamed: C6.2, R6.1
unnamed: C7.2, R7.2, R8.1
unnamed: C9.2, R9.2, R10.1
unnamed: C17.1, R26.1, R27.2
unnamed: C18.1, R28.2, R29.1
unnamed: C21.2, J6.T
unnamed: C22.1, RV5.2
unnamed: C23.1, R31.2, R32.2, R37.1
unnamed: C26.1, RV5.5
unnamed: C27.1, R33.2, R34.2, R40.1
unnamed: C28.1, R38.2
unnamed: C29.2, J6.R
unnamed: C30.1, R41.2
unnamed: D1.2 (A), J1.5, J20.T, U11.2
unnamed: D1.1 (K), R22.2, U11.1
unnamed: D2.2 (A), U8.29 (SPIIO7/GPIO36/FSPICLK/SUBSPICLK)
unnamed: D2.1 (K), R1.1
unnamed: D3.2 (A), U8.30 (SPIDQS/GPIO37/FSPIQ/SUBSPIQ)
unnamed: D3.1 (K), R30.1
unnamed: FB1.1, J13.2
unnamed: J1.4, J20.R, R22.1
unnamed: C6.1, J2.1, U4.2 (A_Out)
unnamed: J2.2, R6.2, U4.4 (B_Out)
unnamed: J7.1, R24.1, U8.32 (MTCK/GPIO39/CLK_OUT3/SUBSPICS1)
unnamed: J7.2, R25.1, U8.33 (MTDO/GPIO40/CLK_OUT2)
unnamed: J8.1, U8.39 (GPIO1/TOUCH1/ADC1_CH0)
unnamed: J8.2, U8.38 (GPIO2/TOUCH2/ADC1_CH1)
unnamed: J8.3, U8.15 (GPIO3/TOUCH3/ADC1_CH2)
unnamed: J8.4, U8.4 (GPIO4/TOUCH4/ADC1_CH3)
unnamed: J8.5, U8.5 (GPIO5/TOUCH5/ADC1_CH4)
unnamed: J8.6, U8.6 (GPIO6/TOUCH6/ADC1_CH5)
unnamed: J8.7, U8.7 (GPIO7/TOUCH7/ADC1_CH6)
unnamed: J8.8, U8.12 (GPIO8/TOUCH8/ADC1_CH7/SUBSPICS1)
unnamed: J10.1, U8.8 (GPIO15/U0RTS/ADC2_CH4/XTAL_32K_P)
unnamed: J11.1, U8.9 (GPIO16/U0CTS/ADC2_CH5/XTAL_32K_N)
unnamed: J14.1, U8.20 (GPIO12/TOUCH12/ADC2_CH1/FSPICLK/FSPIIO6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)
unnamed: J15.1, U8.21 (GPIO13/TOUCH13/ADC2_CH2/FSPIQ/FSPIIO7/S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)
unnamed: J9.4, J18.R, R12.2
unnamed: J9.5, J18.T, R13.2
unnamed: C17.2, J19.1, U1.1, U1.2 (-)
unnamed: C18.2, J21.1, U1.6 (-), U1.7
unnamed: J22.1, U8.11 (GPIO18/U1RXD/ADC2_CH7/CLK_OUT3)
unnamed: J23.1, U8.10 (GPIO17/U1TXD/ADC2_CH6)
unnamed: J24.1, U8.28 (SPIIO6/GPIO35/FSPID/SUBSPID)
unnamed: R35.1, R36.1, SW1.2 (B)
unnamed: C16.1, R26.2, U1.3 (+)
unnamed: C19.1, R29.2, U1.5 (+)
unnamed: C8.1, R8.2, U3.3 (+)
unnamed: C7.1, RV5.1, U3.1, U3.2 (-)
unnamed: C10.1, R10.2, U3.5 (+)
unnamed: C9.1, RV5.4, U3.6 (-), U3.7
unnamed: R3.1, R4.1, R5.2, U4.8 (A+)
unnamed: C3.1, C4.1, R36.2, U4.9 (A-)
unnamed: C4.2, C5.1, R35.2, U4.6 (B-)
unnamed: C11.1, R11.2, SW4.2, U8.3 (EN)
unnamed: R2.2, SW2.1, U8.27 (GPIO0/BOOT)
unnamed: RV3.2, U8.17 (GPIO9/TOUCH9/ADC1_CH8/FSPIHD/SUBSPIHD)
unnamed: RV4.2, U8.18 (GPIO10/TOUCH10/ADC1_CH9/FSPICS0/FSPIIO4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)
unnamed: C22.2, R31.1, U9.3 (+)
unnamed: R38.1, R39.2, U9.2 (-)
unnamed: C26.2, R34.1, U9.5 (+)
unnamed: R41.1, R42.2, U9.6 (-)
PT_BCK: U5.1 (BCK), U8.25 (GPIO48/SPICLK_N/SUBSPICLK_N_DIFF)
PT_DIN: U5.3 (DIN), U8.23 (GPIO21)
PT_L: R7.1, U5.6 (LCH)
PT_R: R9.1, U5.8 (RCH)
PT_WS: U5.2 (WS), U8.24 (GPIO47/SPICLK_P/SUBSPICLK_P_DIFF)
REG_IN: C1.1, C15.2, C24.2, D4.1 (K), D5.1 (K), R32.1, R33.1, SW1.3 (C), U2.3 (VI), U4.3 (V+), U9.8 (V+)
R_TO_SP: C29.1, R4.2, R42.1, U9.7
USB_PWR: D4.2 (A), J17.1 (VBUS)

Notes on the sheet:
CV/PWM SMOOTHING
SPEAKER AMP
POWER INPUT
SCL
POT 1
SDA
DAC
2nd order lpf: fc=21.2k
POT 0
AUDIO AMP
DIP SWITCH
MIDI I/O

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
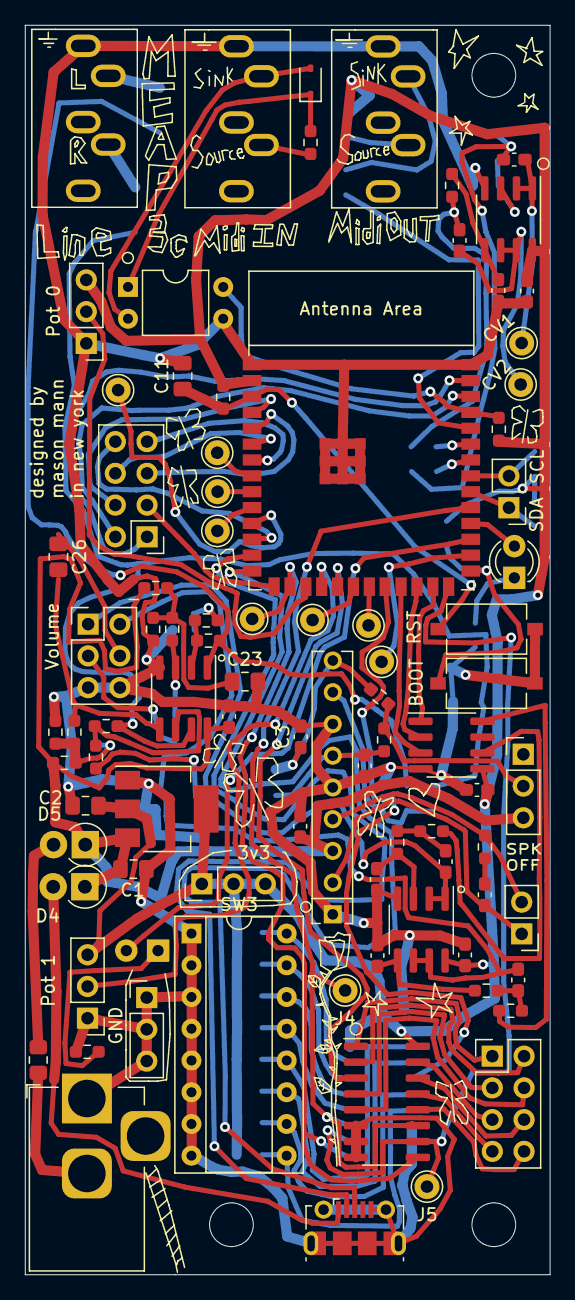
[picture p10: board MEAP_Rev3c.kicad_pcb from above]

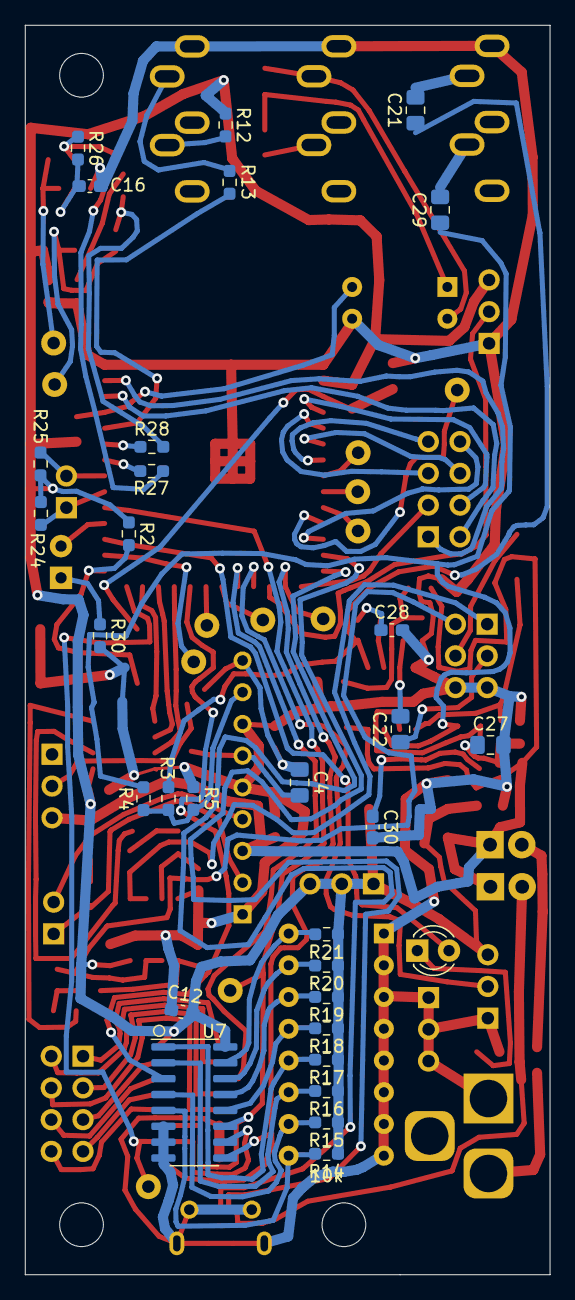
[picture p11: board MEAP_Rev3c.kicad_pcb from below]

Board: 2 copper layers, 42.0 x 100.0 mm, 117 parts (31 on the bottom side), 101 nets.

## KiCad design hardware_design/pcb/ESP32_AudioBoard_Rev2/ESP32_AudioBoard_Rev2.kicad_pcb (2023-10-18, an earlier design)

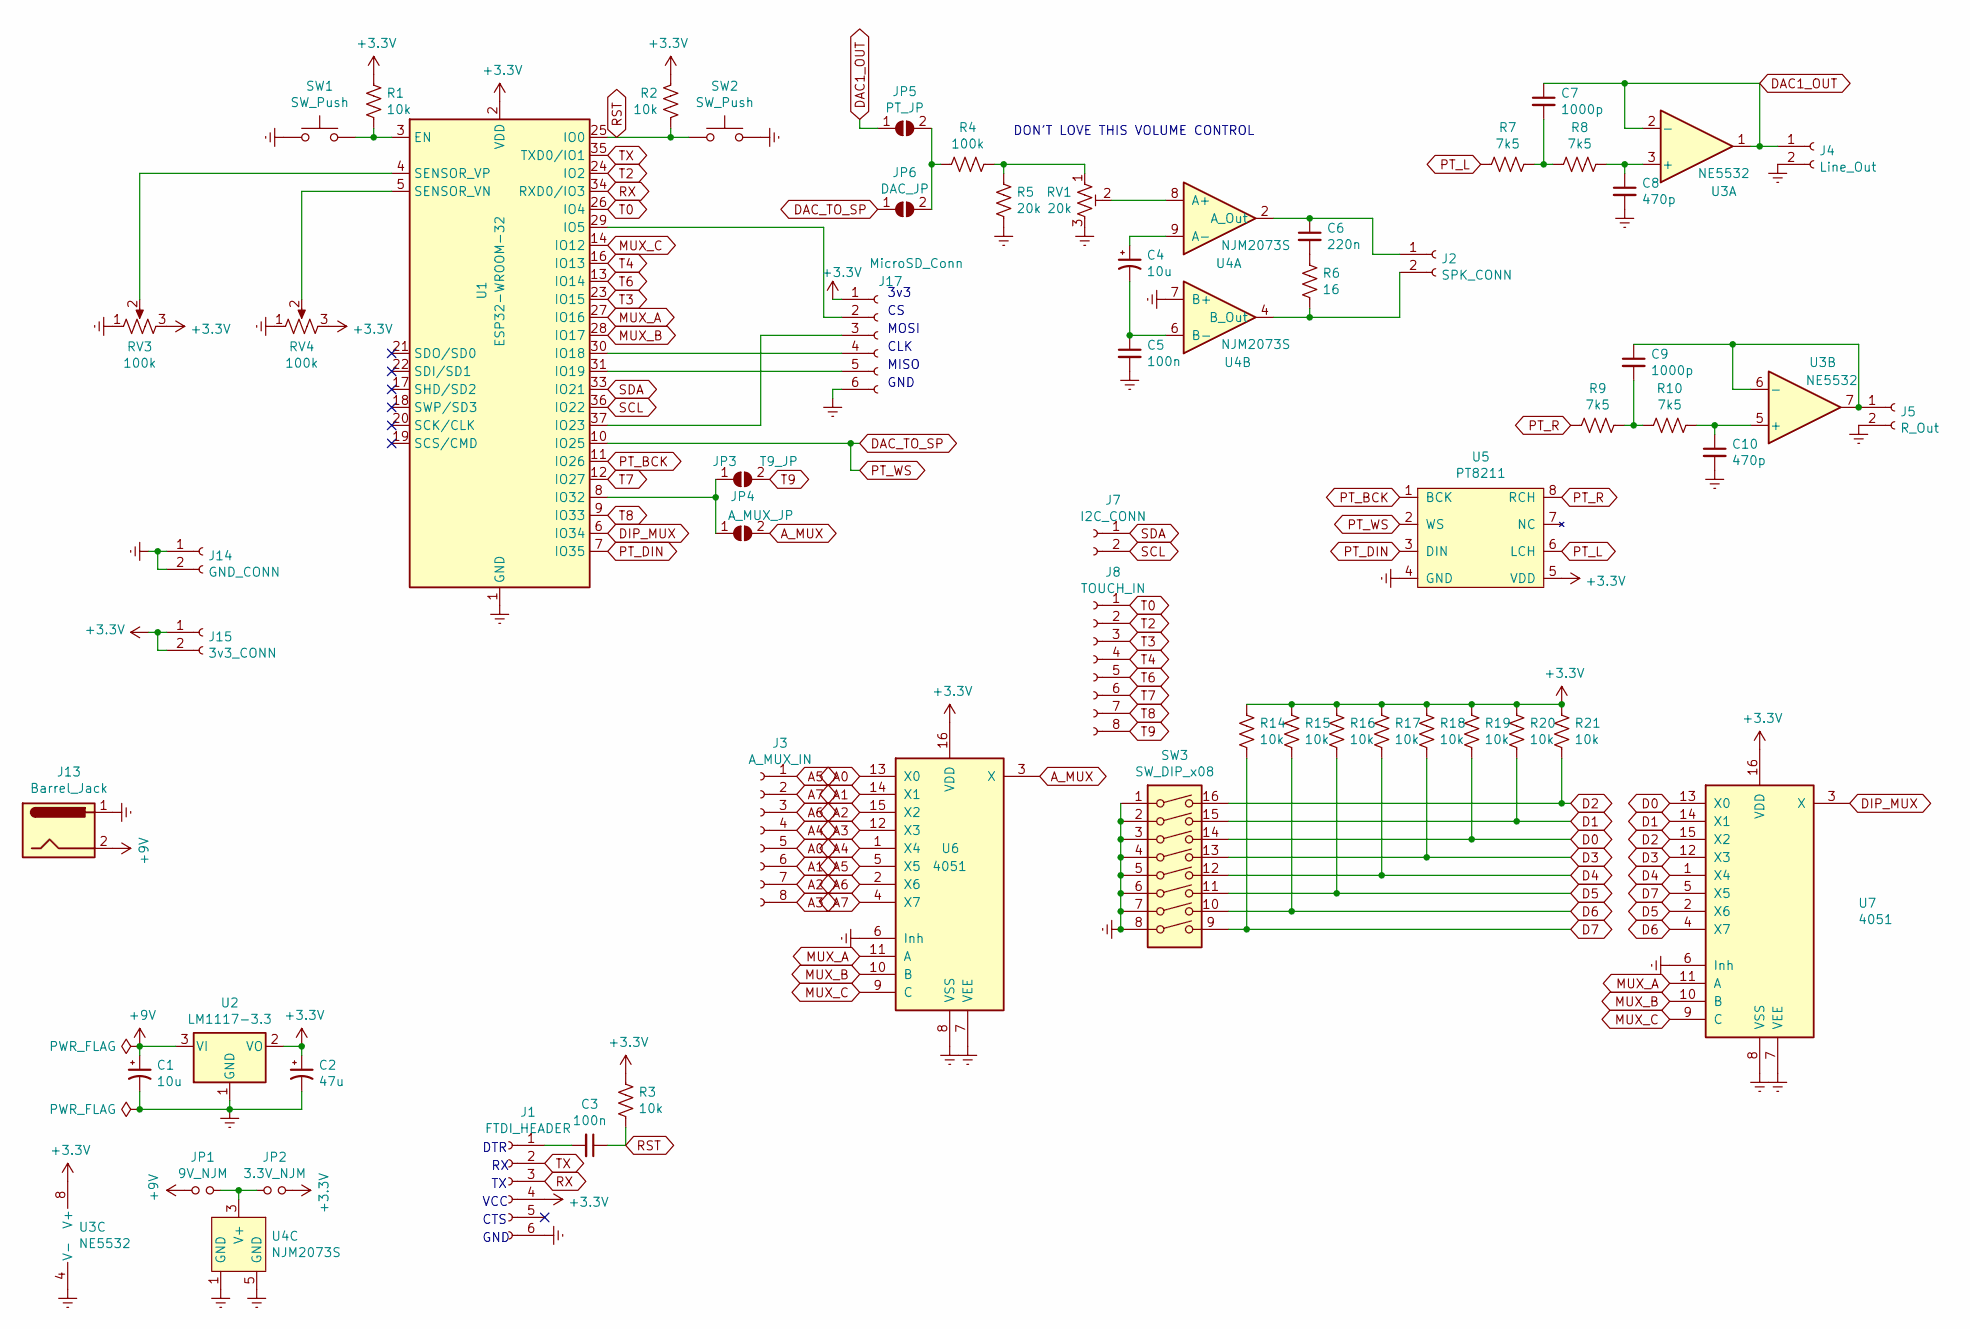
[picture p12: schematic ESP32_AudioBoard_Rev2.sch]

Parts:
C1, C4: 10u; CP_Radial_D5.0mm_P2.0mm_Bigger_Holes
C2: 47u; CP_Radial_D5.0mm_P2.0mm_Bigger_Holes
C3, C5: 100n; C_0805_2012Metric_Pad1.15x1.40mm_HandSolder
C6: 220n; C_0805_2012Metric_Pad1.15x1.40mm_HandSolder
C7, C9: 1000p; C_0805_2012Metric_Pad1.15x1.40mm_HandSolder
C8, C10: 470p; C_0805_2012Metric_Pad1.15x1.40mm_HandSolder
J1: FTDI_HEADER; PinHeader_1x06_P2.54mm_Vertical
J2: SPK_CONN; JST_XH_B2B-XH-A_1x02_P2.50mm_Vertical
J3: A_MUX_IN; PinHeader_1x08_P2.54mm_Vertical
J4: Line_Out; PinHeader_1x02_P2.54mm_Vertical
J5: R_Out; PinHeader_1x02_P2.54mm_Vertical
J7: I2C_CONN; PinHeader_1x02_P2.54mm_Vertical
J8: TOUCH_IN; PinHeader_2x04_P2.54mm_Vertical
J13: Barrel_Jack; BarrelJack_Horizontal
J14: GND_CONN; PinHeader_1x02_P2.54mm_Vertical
J15: 3v3_CONN; PinHeader_1x02_P2.54mm_Vertical
J17: MicroSD_Conn; PinHeader_1x06_P2.54mm_Vertical
JP1: 9V_NJM; SolderJumper-2_P1.3mm_Open_RoundedPad1.0x1.5mm
JP2: 3.3V_NJM; SolderJumper-2_P1.3mm_Open_RoundedPad1.0x1.5mm
JP3: T9_JP; SolderJumper-2_P1.3mm_Open_RoundedPad1.0x1.5mm
JP4: A_MUX_JP; SolderJumper-2_P1.3mm_Open_RoundedPad1.0x1.5mm
JP5: PT_JP; SolderJumper-2_P1.3mm_Open_RoundedPad1.0x1.5mm
JP6: DAC_JP; SolderJumper-2_P1.3mm_Open_RoundedPad1.0x1.5mm
R1, R2, R3, R14, R15, R16, R17, R18, R19, R20, R21: 10k; C_0805_2012Metric_Pad1.15x1.40mm_HandSolder
R4: 100k; C_0805_2012Metric_Pad1.15x1.40mm_HandSolder
R5: 20k; C_0805_2012Metric_Pad1.15x1.40mm_HandSolder
R6: 16; C_0805_2012Metric_Pad1.15x1.40mm_HandSolder
R7, R8, R9, R10: 7k5; R_0805_2012Metric_Pad1.15x1.40mm_HandSolder
RV1: 20k; masonsPotentiometer_Alpha_RD901F-40-00D_Single_Vertical
RV3, RV4: 100k; Potentiometer_Alps_RK097_Single_Horizontal_NoClearance
SW1, SW2: SW_Push; SW_Push_1P1T_NO_6x6mm_H9.5mm
SW3: SW_DIP_x08; DIP-16_W7.62mm_Socket
U1: ESP32-WROOM-32
U2: LM1117-3.3; SOT-223
U3: NE5532; SOIC-8_3.9x4.9mm_P1.27mm
U4: NJM2073S; SIP-9_21.54x3mm_P2.54mm
U5: PT8211; SOIC-8_3.9x4.9mm_P1.27mm
U6, U7: 4051; SOIC-16_3.9x9.9mm_P1.27mm

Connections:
+3V3: C2.1, J1.4, J15.1, J15.2, J17.1, JP2.2, R1.1, R2.1, R3.1, R14.1, R15.1, R16.1, R17.1, R18.1, R19.1, R20.1, R21.1, RV3.3, RV4.3, U1.2 (VDD), U2.2 (VO), U3.8 (V+), U5.5 (VDD), U6.16 (VDD), U7.16 (VDD)
+9V: C1.1, J13.2, JP1.1, U2.3 (VI)
A0: J3.5, U6.13 (X0)
A1: J3.6, U6.14 (X1)
A2: J3.7, U6.15 (X2)
A3: J3.8, U6.12 (X3)
A4: J3.4, U6.1 (X4)
A5: J3.1, U6.5 (X5)
A6: J3.3, U6.2 (X6)
A7: J3.2, U6.4 (X7)
A_MUX: JP4.2 (B), U6.3 (X)
D0: R19.2, SW3.14, U7.13 (X0)
D1: R20.2, SW3.15, U7.14 (X1)
D2: R21.2, SW3.16, U7.15 (X2)
D3: R18.2, SW3.13, U7.12 (X3)
D4: R17.2, SW3.12, U7.1 (X4)
D5: R16.2, SW3.11, U7.2 (X6)
D6: R15.2, SW3.10, U7.4 (X7)
D7: R14.2, SW3.9, U7.5 (X5)
DAC1_OUT: C7.1, J4.1, JP5.1 (A), U3.1, U3.2 (-)
DAC_TO_SP: JP6.1 (A), U1.10 (IO25), U5.2 (WS)
DIP_MUX: U1.6 (IO34), U7.3 (X)
Earth: C1.2, C2.2, C5.2, C8.2, C10.2, J1.6, J4.2, J5.2, J13.1, J14.1, J14.2, J17.6, R5.1, RV1.3, RV3.1, RV4.1, SW1.1, SW2.1, SW3.1, SW3.2, SW3.3, SW3.4, SW3.5, SW3.6, SW3.7, SW3.8, U1.1 (GND), U1.15 (GND), U1.38 (GND), U2.1 (GND), U3.4 (V-), U4.1 (GND), U4.5 (GND), U4.7 (B+), U5.4 (GND), U6.6 (Inh), U6.7 (VEE), U6.8 (VSS), U7.6 (Inh), U7.7 (VEE), U7.8 (VSS)
MUX_A: U1.27 (IO16), U6.11 (A), U7.11 (A)
MUX_B: U1.28 (IO17), U6.10 (B), U7.10 (B)
MUX_C: U1.14 (IO12), U6.9 (C), U7.9 (C)
unnamed: C3.2, J1.1
unnamed: C4.1, U4.9 (A-)
unnamed: C4.2, C5.1, U4.6 (B-)
unnamed: C6.1, J2.1, U4.2 (A_Out)
unnamed: C6.2, R6.1
unnamed: C7.2, R7.2, R8.1
unnamed: C8.1, R8.2, U3.3 (+)
unnamed: C9.1, J5.1, U3.6 (-), U3.7
unnamed: C9.2, R9.2, R10.1
unnamed: C10.1, R10.2, U3.5 (+)
unnamed: J2.2, R6.2, U4.4 (B_Out)
unnamed: J17.2, U1.29 (IO5)
unnamed: J17.3, U1.37 (IO23)
unnamed: J17.4, U1.30 (IO18)
unnamed: J17.5, U1.31 (IO19)
unnamed: JP1.2, JP2.1, U4.3 (V+)
unnamed: JP3.1 (A), JP4.1 (A), U1.8 (IO32)
unnamed: JP5.2 (B), JP6.2 (B), R4.2
unnamed: R1.2, SW1.2, U1.3 (EN)
unnamed: R4.1, R5.2, RV1.1
unnamed: RV1.2, U4.8 (A+)
unnamed: RV3.2, U1.4 (SENSOR_VP)
unnamed: RV4.2, U1.5 (SENSOR_VN)
PT_BCK: U1.11 (IO26), U5.1 (BCK)
PT_DIN: U1.7 (IO35), U5.3 (DIN)
PT_L: R7.1, U5.6 (LCH)
PT_R: R9.1, U5.8 (RCH)
RST: C3.1, R2.2, R3.2, SW2.2, U1.25 (IO0)
RX: J1.3, U1.34 (RXD0/IO3)
SCL: J7.2, U1.36 (IO22)
SDA: J7.1, U1.33 (IO21)
T0: J8.1, U1.26 (IO4)
T2: J8.2, U1.24 (IO2)
T3: J8.3, U1.23 (IO15)
T4: J8.4, U1.16 (IO13)
T6: J8.5, U1.13 (IO14)
T7: J8.6, U1.12 (IO27)
T8: J8.7, U1.9 (IO33)
T9: J8.8, JP3.2 (B)
TX: J1.2, U1.35 (TXD0/IO1)

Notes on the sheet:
DTR
VCC
CTS
GND
DON’T LOVE THIS VOLUME CONTROL
3v3
MOSI
CLK
MISO



Board: 2 copper layers, 42.0 x 100.0 mm, 58 parts (24 on the bottom side), 66 nets.

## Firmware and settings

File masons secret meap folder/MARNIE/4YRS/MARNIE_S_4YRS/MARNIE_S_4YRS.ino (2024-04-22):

/*
  Sampler half of MARNIE patch for 4 years of fish

  MEAP Pot 0:
  MEAP Pot 1:

  DIP 1: UP = external clock |||| DOWN = internal clock
  DIP 2:
  DIP 3: 
  DIP 4:
  DIP 5: 
  DIP 6:
  DIP 7:
  DIP 8:

  MARNIE Pot 0:
  MARNIE Pot 1:
  MARNIE Pot 2: Portamento Range
  MARNIE Pot 3: Cutoff Randomization Range

  MARNIE Pot 4: Filter Cutoff
  MARNIE Pot 5: Amplitude Envelope Attack
  MARNIE Pot 6: Filter Resonance
  MARNIE Pot 7: Amplitude Envelope Release
  
  MARNIE Switch 0:
  MARNIE Switch 1:
  MARNIE Switch 2:
  MARNIE Switch 3: RESTING = sample looping off |||| ENGAGED = sample looping on 
  MARNIE Switch 4:
  MARNIE Switch 5:

  MIDI CONTROLLER KNOB 1 (cc71):
  MIDI CONTROLLER KNOB 2 (cc74):
  MIDI CONTROLLER KNOB 3 (cc84):
  MIDI CONTROLLER KNOB 4 (cc7):
  MIDI CONTROLLER KNOB 5 (cc91):
  MIDI CONTROLLER KNOB 6 (cc93):
  MIDI CONTROLLER KNOB 7 (cc5):  Change program (chooses sample)
  MIDI CONTROLLER KNOB 8 (cc10): Change pattern bank
  MIDI Repeat Button: Stop all sampler patterns
  MIDI Rewind Button: Flush all MIDI notes
  MIDI Start Button/Message:
  MIDI Stop Button/Message:
  MIDI Record Button:
  

  Mason Mann, CC0
 */

#include <Meap.h>
#include "MySample.h"
#include <LinkedList.h>
#include "sample_includes.h"
#include "MyPortamento.h"
#include "SamplePattern.h"
#include "patterns.h"
#include "MyPDResonant.h"

#define CONTROL_RATE 64  // Hz, powers of 2 are most reliable

#define NUM_PROGRAMS 35

#define DEBUG 1
#define PROBEMIDI 1

#if DEBUG == 1
#define debug(x) Serial.print(x)
#define debugln(x) Serial.println(x)
#else
#define debug(x)
#define debugln(x)
#endif

#if PROBEMIDI == 1
#define probemidi(x) Serial.print(x)
#define probemidiln(x) Serial.println(x)
#else
#define probemidi(x)
#define probemidiln(x)
#endif

#define POLYPHONY 40
#define MAX_SAMPLE_LENGTH 300000
#define MIDI_NOTE_CHANNEL 1
#define MIDI_PAD_CHANNEL 10
#define MIDI_OUT_CHANNEL 5  // out to cz101

enum sequencerStates {
  PAUSED,
  PLAYING
};

enum clockModes {
  CK_INTERNAL,
  CK_EXTERNAL
};

enum retrigModes {
  RT_NONE,
  RT_QUARTER,
  RT_EIGHTH,
  RT_SIXTEENTH,
  RT_THIRTYSECOND,
  RT_SIXTYFOURTH
};


int button_pins[6] = { 15, 16, 12, 13, 18, 35 };
int button_vals[6] = { 0, 0, 0, 0, 0, 0 };
int last_button_vals[6] = { 0, 0, 0, 0, 0, 0 };

Meap meap;

MIDI_CREATE_INSTANCE(HardwareSerial, Serial1, MIDI);

// Sample voices
MySample<MAX_SAMPLE_LENGTH, AUDIO_RATE> sample[POLYPHONY];  //maybe change the MAX_SAMPLE_LENGTH? calc how it corresponds to seconds etc
float default_freq;
float sample_freq[POLYPHONY];
bool sample_active[POLYPHONY] = { false };
int curr_voice = 0;  // voice from sample[] array being used

int curr_program = 0;  // current midi program, primarily used to choose sample

ADSR<CONTROL_RATE, AUDIO_RATE, unsigned int> sample_env[POLYPHONY];
int sample_gain[POLYPHONY];
int attack_time = 1;
int release_time = 500;
bool attack_flag = false;
bool release_flag = false;

MyPortamento<CONTROL_RATE> portamento[POLYPHONY];



class MidiNoteVoice {
public:
  int note_num;
  int voice_num;
  float frequency;
  bool port_done;
  uint32_t port_end_time;
};

class PatternNote {
public:
  uint8_t note_num;
  uint16_t voice_num;
  uint8_t channel_num;
  uint32_t end_time;
};

LinkedList<MidiNoteVoice *> voiceQueue = LinkedList<MidiNoteVoice *>();

LinkedList<PatternNote *> patternQueue = LinkedList<PatternNote *>();


MultiResonantFilter<uint8_t> filter;
int cutoff = 255;
int resonance = 127;
bool cutoff_flag = false;
bool resonance_flag = false;
int rand_cutoff_range = 0;

// retrigger pads
int retrigger_mode = 0;  // 0 = none, 1 =

// MIDI clock timer
uint32_t midi_timer = 0;
uint32_t midi_micros = 10000;
int midi_step_num = 0;
bool start_flag = false;
bool stop_flag = false;
int midi_clock_mode = CK_INTERNAL;

// pitchbend
int pitchbend_semitones = 2;  // num of semitones the pitchbend wheel bends
float bend_amount = 1;

//portamento
uint16_t port_length = 0;  // length of portamento in milliseconds
Q16n16 last_port_note = 0;

// guitar chord voice
int chord_tonic = -1;
int chord_qualities[12] = { 7, 9, 8, 10, 8, 7, 9, 7, 9, 8, 7, 9 };  // 7=maj 8=min 9=dim 10=aug

// pattern stuff

int curr_pattern_bank = 0;

// digital synth voices
MyPDResonant pd_voice;
Portamento<CONTROL_RATE> pdPortamento;

// for easing timing of pattern starting
uint32_t last_sixteenth_time = 0;     /**< keeps track of the time in ms that the last 16th note happened */
uint32_t half_sixteenth_length = 100; /**< half of the period in ms of one sixteenth note */


void setup() {
  Serial.begin(115200);                      // begins Serial communication with computer
  Serial1.begin(31250, SERIAL_8N1, 43, 44);  // sets up MIDI: baud rate, serial mode, rx pin, tx pin
  startMozzi(CONTROL_RATE);                  // starts Mozzi engine with control rate defined above
  meap.begin();

  // initialize samples
  default_freq = (float)piano_SAMPLERATE / (float)MAX_SAMPLE_LENGTH;
  for (int i = 0; i < POLYPHONY; i++) {
    sample[i].setTable(piano_DATA);
    sample[i].setEnd(piano_NUM_CELLS);
    sample_freq[i] = default_freq;
    sample[i].setFreq(sample_freq[i]);
    sample_gain[i] = 0;
    sample_env[i].setAttackTime(attack_time);
    sample_env[i].setSustainTime(4294967295);  // max value of unsigned 32 bit int,, notes can sustain for arbitrary time limit
    sample_env[i].setReleaseTime(release_time);
    sample_env[i].setADLevels(255, 255);
  }

  // initialize filter
  filter.setCutoffFreq(cutoff);
  filter.setResonance(resonance);

  // initialize tempo to 120 BPM
  midi_micros = meap.midiPulseMicros(120);
  half_sixteenth_length = midi_micros * 3 / 1000;          // for fixing timing on pattern triggering with touch pads

  // set up organ switch pins
  for (int i = 0; i < 6; i++) {
    pinMode(button_pins[i], INPUT_PULLUP);
  }

  //digital voice setup
  pdPortamento.setTime(500);

  patternSetup();
}


void loop() {
  audioHook();
  if (MIDI.read())  // Is there a MIDI message incoming ?
  {
    midiEventHandler();
  }

  // handle generating midi clock
  if (midi_clock_mode == CK_INTERNAL) {
    uint32_t t = micros();
    if (t > midi_timer) {
      midi_timer = t + midi_micros;
      MIDI.sendRealTime(midi::Clock);
      clockStep();
    }
  }
}


void updateControl() {
  meap.readPots();
  meap.readTouch();
  meap.readDip();
  meap.readAuxMux();
  updateButtons();

  // MARNIE Pot Controls
  cutoff = map(meap.aux_mux_vals[4], 0, 4095, 0, 255);
  filter.setCutoffFreq(cutoff);

  resonance = map(meap.aux_mux_vals[6], 0, 4095, 0, 255);
  filter.setResonance(resonance);

  attack_time = meap.aux_mux_vals[5];
  release_time = meap.aux_mux_vals[7];

  // update portamento
  port_length = map(meap.aux_mux_vals[2], 0, 4095, 0, 1000);
  // pdPortamento.setTime(port_length);
  handlePortamento();

  // update rand cutoff range
  rand_cutoff_range = map(meap.aux_mux_vals[3], 0, 4095, 0, 127);
  // if (rand_cutoff_range <= 2) {
  //   rand_cutoff_range = 0;
  // }


  // update amplitude envelopes
  for (int i = 0; i < POLYPHONY; i++) {
    sample_env[i].update();
  }

  // read tempo from pot 0
  midi_micros = meap.midiPulseMicros((int)map(meap.pot_vals[0], 0, 4095, 80, 160));
  half_sixteenth_length = midi_micros * 3 / 1000;          // for fixing timing on pattern triggering with touch pads

  //handle pattern array
  for (int bank = 0; bank < NUM_PATTERN_BANKS; bank++) {
    for (int i = 0; i < 8; i++) {
      patterns[bank][i].cycle();
      if (patterns[bank][i].step_flag) {
        patterns[bank][i].step_flag = false;
        step(patterns[bank][i]);
      }
    }
  }

  // update PDresonant voice
  // pd_voice.freq = (int)Q16n16_to_float(pdPortamento.next());// fixed to int
  // pd_voice.freq = mtof((int)Q16n16_to_float(pdPortamento.next()));
  // Q16n16 my_pd_freq;
  // my_pd_freq = pdPortamento.next();
  // float my_float_freq = Q16n16_to_float(my_pd_freq);

  // debug(my_float_freq);
  // debug(" ");
  // debugln(mtof(my_float_freq));

  // pd_voice.noteUpdate((int)my_float_freq);
  pd_voice.update();

  // ends notes triggered by patterns
  cleanPatternQueue();
}


AudioOutput_t updateAudio() {
  int out_sample = 0;
  // add all samples to envelope
  for (int i = 0; i < POLYPHONY; i++) {
    sample_gain[i] = sample_env[i].next();
    out_sample += sample[i].next() * sample_gain[i];
  }
  //add pd voice
  out_sample = out_sample + (pd_voice.next() << 8);  // calculate pd output and shift up to match volume of samples
  // send output through filter
  filter.next(out_sample);
  int filtered_out;
  if (meap.dip_vals[7]) {
    filtered_out = filter.band();
  } else {
    filtered_out = filter.low();
  }
  //send output to DAC
  return StereoOutput::fromAlmostNBit(19, filtered_out, filtered_out);
}

void Meap::updateTouch(int pad_num, bool pressed) {
  if (pressed) {
    if (patterns[curr_pattern_bank][pad_num].active) {
      patterns[curr_pattern_bank][pad_num].stop();
    } else {
      patterns[curr_pattern_bank][pad_num].start();
      // check closest sixteenth note here! using ppq???? or maybe i store time with millis or micros?
      uint32_t curr_time = millis();
      if (curr_time > last_sixteenth_time && curr_time < last_sixteenth_time + half_sixteenth_length) {
        debugln("pressed late, accomodating!");
        //closest sixteenth is in the past,, do something here!!!
        // use step function
        patterns[curr_pattern_bank][pad_num].start_flag = false;
        step(patterns[curr_pattern_bank][pad_num]);
      }
    }
  }

  switch (pad_num) {
    case 0:
      if (pressed) {  // Pad 1 pressed
      } else {        // Pad 1 released
      }
      break;
    case 1:
      if (pressed) {  // Pad 2 pressed
      } else {        // Pad 2 released
      }
      break;
    case 2:
      if (pressed) {  // Pad 3 pressed
      } else {        // Pad 3 released
      }
      break;
    case 3:
      if (pressed) {  // Pad 4 pressed
      } else {        // Pad 4 released
      }
      break;
    case 4:
      if (pressed) {  // Pad 5 pressed
      } else {        // Pad 5 released
      }
      break;
    case 5:
      if (pressed) {  // Pad 6 pressed
      } else {        // Pad 6 released
      }
      break;
    case 6:
      if (pressed) {  // Pad 7 pressed
      } else {        // Pad 7 released
      }
      break;
    case 7:
      if (pressed) {  // Pad 8 pressed
      } else {        // Pad 8 released
      }
      break;
  }
}

void Meap::updateDip(int number, bool up) {
  switch (number) {
    case 0:
      if (up) {  // DIP 1 up
        midi_clock_mode = CK_EXTERNAL;
      } else {  // DIP 1 down
        midi_clock_mode = CK_INTERNAL;
      }
      break;
    case 1:
      if (up) {  // DIP 2 up

      } else {  // DIP 2 down
      }
      break;
    case 2:
      if (up) {  // DIP 3 up
      } else {   // DIP 3 down
      }
      break;
    case 3:
      if (up) {  // DIP 4 up

      } else {  // DIP 4 down
      }
      break;
    case 4:
      if (up) {  // DIP 5 up

      } else {  // DIP 5 down
      }
      break;
    case 5:
      if (up) {  // DIP 6 up

      } else {  // DIP 6 down
      }
      break;
    case 6:
      if (up) {  // DIP 7 up

      } else {  // DIP 7 down
      }
      break;
    case 7:
      if (up) {  // DIP 8 up

      } else {  // DIP 8 down
      }
      break;
  }
}

void updateButtons() {
  for (int i = 0; i < 6; i++) {
    // Read the buttons
    button_vals[i] = digitalRead(button_pins[i]);
    // Check if state has changed
    if (button_vals[i] != last_button_vals[i]) {
      switch (i) {
        case 0:
          if (button_vals[i]) {  // button 0 pressed
            debugln("B0 pressed");
          } else {  // button 0 released
            debugln("B0 released");
          }
          break;
        case 1:
          if (button_vals[i]) {  // button 1 pressed
            debugln("B1 pressed");
          } else {  // button 1 released
            debugln("B1 released");
          }
          break;
        case 2:
          if (button_vals[i]) {  // button 2 pressed
            debugln("B2 pressed");
          } else {  // button 2 released
            debugln("B2 released");
          }
          break;
        case 3:                  // SAMPLE LOOPING MODE
          if (button_vals[i]) {  // button 3 pressed
            debugln("B3 pressed");
            for (int i = 0; i < POLYPHONY; i++) {
              sample[i].setLoopingOn();
            }
          } else {  // button 3 released
            debugln("B3 released");
            for (int i = 0; i < POLYPHONY; i++) {
              sample[i].setLoopingOff();
            }
          }
          break;
        case 4:
          if (button_vals[i]) {  // button 4 pressed
            debugln("B4 pressed");
          } else {  // button 4 released
            debugln("B4 released");
          }
          break;
        case 5:
          if (button_vals[i]) {  // button 5 pressed
            debugln("B5 pressed");
          } else {  // button 5 released
            debugln("B5 released");
          }
          break;
      }
    }
    last_button_vals[i] = button_vals[i];
  }
}


//executes when a clock step is received
void clockStep() {

  if (midi_step_num % 24 == 0) {  // quarter note
    if (retrigger_mode == RT_QUARTER) {
      retriggerNotes(true);
    }
  }

  if (midi_step_num % 12 == 0) {  // eighth note
    randomizeCutoff(rand_cutoff_range);
    if (retrigger_mode == RT_EIGHTH) {
      retriggerNotes(true);
    }
  }

  if (midi_step_num % 6 == 0) {  // sixteenth note
    last_sixteenth_time = millis();
    if (meap.irand(0, 4) == 0) {
      randomizeCutoff(rand_cutoff_range);
    }
    if (retrigger_mode == RT_SIXTEENTH) {
      retriggerNotes(true);
    }

    //send triggers to patterns
    for (int bank = 0; bank < NUM_PATTERN_BANKS; bank++) {
      for (int i = 0; i < 8; i++) {
        patterns[bank][i].incrementClock(midi_step_num);
      }
    }
  }

  if (midi_step_num % 3 == 0) {  // thirtysecond note
    if (retrigger_mode == RT_THIRTYSECOND) {
      retriggerNotes(true);
    }
  }

  midi_step_num = (midi_step_num + 1) % 24;
}

/**
* @brief Randomizes cutoff of filter.
*
* @param range is the range to randomize filter over in "percentage"
*/
void randomizeCutoff(int range) {
  if (range > 2) {
    debugln("cutoff rand");
    // range = range << 1;  // maps input range to 0-200
    int rand_cutoff = cutoff + meap.irand(-range, range);
    // clip to range 0-255
    if (rand_cutoff > 255) {
      rand_cutoff = 255;
    } else if (rand_cutoff < 0) {
      rand_cutoff = 0;
    }
    filter.setCutoffFreq(rand_cutoff);
  }
}


/**
* @brief Handles turning on sample notes.
*
* @param note is the MIDI note number to turn on
* @param velocity is the velocity of the MIDI note to turn on (NOT CURRENTLY USED)
* @param channel is the velocity of the MIDI note to turn on (NOT CURRENTLY USED)
* @param pgm_override overrides the current program to play note on specified program 
*/
void noteOnHandler(int note, int velocity, int channel, int pgm_override) {

  if (channel == MIDI_NOTE_CHANNEL) {  // check on which channel we received the MIDI noteOn
    if (curr_program < NUM_SAMPLES) {  // play a sample
      // choose voice to play
      int my_program = curr_program;
      if (pgm_override = !-1) {
        my_program = pgm_override;
      }
      // handle choosing chords for the guitar chord voice
      if (my_program >= 7 && my_program <= 10) {  // guitar chord voice
        if (chord_tonic == -1) {                  // tonic hasn't been chosen yet, choose it now and don't play a note
          chord_tonic = note % 12;
          return;
        } else {  // tonic has been chosen, choose correct chord
          int mod_note = note % 12;
          if (mod_note < chord_tonic) {
            mod_note += 12;
          }
          int root_diff = mod_note - chord_tonic;  // how many semitones above tonic is the note
          my_program = chord_qualities[root_diff];
        }
      }
      // find a free voice
      curr_voice = -1;
      for (int i = 0; i < POLYPHONY; i++) {
        if (!sample_env[i].playing()) {
          sample_active[i] = true;
          curr_voice = i;
          break;
        }
      }
      debugln(curr_voice);

      if (curr_voice != -1) {  // if any voice is free, play the note, if not don't play it!
        sample[curr_voice].setTable(samples_list[my_program]);
        sample[curr_voice].setEnd(samples_lengths[my_program]);

        // calculate frequency offset for sample
        float diff = note - 60;
        sample_freq[curr_voice] = default_freq * pow(2, diff / 12.f);  // calc freq of sample

        // update the envelope
        sample_env[curr_voice].setAttackTime(map(attack_time, 0, 4095, 1, 2000));
        sample_env[curr_voice].setReleaseTime(map(release_time, 0, 4095, 1, 2000));

        // start the note
        sample[curr_voice].setFreq(sample_freq[curr_voice] * bend_amount);  // set frequency of sample
        sample_env[curr_voice].noteOn();
        sample[curr_voice].start();


        // keep track of note in active notes queue
        MidiNoteVoice *myNote = new MidiNoteVoice();  // create object to keep track of note num, voice num and freq
        myNote->note_num = note;
        myNote->voice_num = curr_voice;
        myNote->frequency = sample_freq[curr_voice];
        if (port_length == 0 || voiceQueue.size() == 0) {  // don't apply portamento if port time is zero or if no notes are active
          myNote->port_done = true;
          myNote->port_end_time = 0;
        } else {
          myNote->port_done = false;
          myNote->port_end_time = millis() + port_length;
          portamento[curr_voice].setTime(0);
          portamento[curr_voice].start(last_port_note);
          portamento[curr_voice].next();  // jump this voice to the prev note pitch, this is really hacky
          portamento[curr_voice].next();
          portamento[curr_voice].setTime(port_length);
          portamento[curr_voice].start(float_to_Q16n16(sample_freq[curr_voice]));
        }

        last_port_note = float_to_Q16n16(sample_freq[curr_voice]);  // set this as last note played for portamento
        voiceQueue.add(myNote);                                     // add to active notes queue
      }
    } else if (curr_program == NUM_SAMPLES) {  // pd resonant voice
      pd_voice.setPDEnv(attack_time, attack_time);
      // debugln((uint8_t)note);
      // if(voiceQueue.size() > 0){
      //   pdPortamento.setTime(port_length);
      // } else{
      //   pdPortamento.setTime(0);
      // }

      // pdPortamento.start((uint8_t)note);
      // pd_voice.noteOn(1, note, 127);  // channel has no effect here
      // Q16n16 my_pd_freq;
      // my_pd_freq = pdPortamento.next();
      // float my_float_freq = Q16n16_to_float(my_pd_freq);

      pd_voice.noteOn(1, note, 127);  // channel has no effect here
    }
  }

  if (channel == MIDI_PAD_CHANNEL) {  // HANDLING PADS FRROM MIDI KEYBOARD
    switch (note) {
      case 50:
        if (retrigger_mode == RT_QUARTER) {
          retrigger_mode = RT_NONE;
        } else {
          retrigger_mode = RT_QUARTER;
        }
        break;
      case 45:
        if (retrigger_mode == RT_EIGHTH) {
          retrigger_mode = RT_NONE;
        } else {
          retrigger_mode = RT_EIGHTH;
        }
        break;
      case 51:
        if (retrigger_mode == RT_SIXTEENTH) {
          retrigger_mode = RT_NONE;
        } else {
          retrigger_mode = RT_SIXTEENTH;
        }
        break;
      case 49:
        if (retrigger_mode == RT_THIRTYSECOND) {
          retrigger_mode = RT_NONE;
        } else {
          retrigger_mode = RT_THIRTYSECOND;
        }
        break;
    }
  }
}


/**
* @brief Handles turning off sample notes.
*
* @param note is the MIDI note number to turn off
* @param channel is the MIDI channel of the note to turn off
*/
void noteOffHandler(int note, int channel) {
  if (channel == MIDI_NOTE_CHANNEL) {
    if (curr_program < NUM_SAMPLES) {
      int queue_size = voiceQueue.size();
      if (queue_size > 0) {
        bool entries_to_delete[queue_size];
        MidiNoteVoice *myNote;
        // loop through voice queue searching for note
        for (int i = 0; i < queue_size; i++) {
          myNote = voiceQueue.get(i);
          if (note == myNote->note_num) {
            sample_env[myNote->voice_num].noteOff();   // turn off note
            sample_active[myNote->voice_num] = false;  // free up voice
            // delete (myNote);
            entries_to_delete[i] = true;
          } else {
            entries_to_delete[i] = false;
          }
        }

        // delete tagged notes starting at end of array
        for (int i = queue_size - 1; i >= 0; i--) {
          if (entries_to_delete[i]) {
            delete (voiceQueue.get(i));
            voiceQueue.remove(i);
          }
        }
      }
    } else if (curr_program == NUM_SAMPLES) {
      pd_voice.noteOff(channel, note, 0);
    }
  }

  if (channel == MIDI_PAD_CHANNEL) {
  }
}

/**
* @brief Handles changing MIDI programs
*
* @param program_num is the MIDI program to change to
*/
void programChangeHandler(int program_num) {
  //GENERIC SAMPLE CHANGE
  if (program_num >= 0 && program_num < NUM_PROGRAMS) {
    curr_program = program_num;  // set current program to received program

    switch (program_num) {  // do we need to do anything for specific programs
      case 7:               // Guitar chord nonsense
        chord_tonic = -1;
        break;
    }
  }
}
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

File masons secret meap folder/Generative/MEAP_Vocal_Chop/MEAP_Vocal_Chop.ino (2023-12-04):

/*
  Press touch pads to toggle sequences on/off
  Pot #0 controls how often glitches occur (entropy)
  Pot #1 controls length of envelopes allowed in glitches (cw = long notes, ccw = short notes)

  Mason Mann, CC0
 */

#include <MozziGuts.h>
#include <Sample.h>
#include <mozzi_rand.h>
#include <mozzi_midi.h>
#include <Mux.h>
#include <SPI.h>
#include <EventDelay.h>
#include <ADSR.h>
#include "vox.h"

#define CONTROL_RATE 128 // Hz, powers of 2 are most reliable

#define NUM_SAMP 6

using namespace admux;


// variables for DIP switches
Mux mux(Pin(34, INPUT, PinType::Digital), Pinset(16, 17, 12));
int dipPins[] = {5, 6, 7, 4, 3, 0, 2, 1};
int dipVals[] = {1, 1, 1, 1, 1, 1, 1, 1};
int prevDipVals[] = {1, 1, 1, 1, 1, 1, 1, 1};

// variables for capacitive touch pads
int touchPins[] = {2, 13, 27, 32, 4, 15, 14, 33};
int touchAvgs[] = {100, 100, 100, 100, 100, 100, 100, 100};
int touchVals[] = {0, 0, 0, 0, 0, 0, 0, 0};
int prevTouchVals[] = {0, 0, 0, 0, 0, 0, 0, 0};
int touchThreshold = 20;

// variables for potentiometers
int potVals[] = {0, 0};

// variables for samples
Sample <vox_NUM_CELLS, AUDIO_RATE> samp[NUM_SAMP](vox_DATA);
float sampFreq[NUM_SAMP];
float voxFreq = 0;

EventDelay myTimer[NUM_SAMP];
int myTime[NUM_SAMP];

EventDelay envTimer[NUM_SAMP];
int noteLen = 50;
int myGain[NUM_SAMP];
int mute[NUM_SAMP];
int pitchOffset[NUM_SAMP];

int masterGains[NUM_SAMP];

EventDelay clockTimer;
int clockLen = 160;

int majScale[] = {0, 2, 4, 5, 7, 9, 11}; // template for building major scale on top of 12TET
int scaleRoot = 48; // root of major scale

int seventh[] = {0, 2, 4, 6}; // template for triad on top of major scale
int chordRoot = 0; // root of triad




//PATTERNS

class Sequence {       // The class
  public:             // Access specifier
    int notes[50];
    int times[50];
    int lengths[50];
    int index = 0;
    int length = 0;
    int beatCounter = 0;

    float currSampleMul = 0;
    int currMidiOffset = 0;
    int currNoteLength = 0;
    bool ready = false;

    void update(int offset){
      beatCounter++;
      if (beatCounter >= times[index]){
        beatCounter = 0;
        index++;
        if(index >= length){
          index = 0;
        }
        //set freq
        currMidiOffset = getMidiOfStep(index);
        currSampleMul = getSampleOffOfStepOffset(index, offset);
        currNoteLength = getLengthOfStep(index);
        ready = true;
      }
    }

  float scaleDegtoSemi(int scaleDeg)
  {
        int scaleOct = 0;
        while(scaleDeg < 0){ // bring up to octave
          scaleDeg += 7;
          scaleOct -= 1;
        }
        while(scaleDeg > 6){ // bring down to octave
          scaleDeg -= 7;
          scaleOct += 1;
        }
        float mySemi = majScale[scaleDeg] + 12 * scaleOct;
        return mySemi;
  }

  int getMidiOfStep(int stepNum){
    return scaleDegtoSemi(notes[stepNum]);
  }

  float getSampleOffOfStep(int stepNum){
    return pow(2, (float)getMidiOfStep(stepNum) / 12.0);
  }

  float getSampleOffOfStepOffset(int stepNum, int offset){
    return pow(2, (float)(scaleDegtoSemi(notes[stepNum] + offset)) / 12.0);
  }

  int getLengthOfStep(int stepNum){
    return lengths[stepNum] * clockLen;
  }
};

Sequence seq[NUM_SAMP];


int glitchFactor = 0;

void setup(){
  Serial.begin(115200);
  pinMode(34, INPUT);
  startMozzi(CONTROL_RATE);

  randomSeed(10); // initializes random number generator
  xorshiftSeed((long)random(1000));

  //setup all the voice objects
  voxFreq = (float)vox_SAMPLERATE / (float) vox_NUM_CELLS;
  for (int i = 0; i < NUM_SAMP; i++){
    sampFreq[i] = (float)(voxFreq * pow(2, (float)(2*i)/12.0));
    samp[i].setFreq(sampFreq[i]);
    myTime[i] = 200 + 100 * i;
    myTimer[i].start(myTime[i]);
    myGain[i] = 0;
    masterGains[i] = 255;
    mute[i] = 0;
    pitchOffset[i] = 0;
  }

  clockTimer.start(clockLen);

  // create seq 0
  int m1N[] = {-5, -1, 0, 0, 2, -1}; // E3 B3 C4 C4 E4 B3 = -5 -1 0 0 2 -1
  int m1T[] = {12, 4, 22, 9, 1, 12}; // 0 12 16 38 47 48
  int m1L[] = {12, 4, 18, 9, 1, 12}; // 12 4 18 9 1 12
  int l1 = sizeof(m1N)/sizeof(int);
  seq[0].length = l1;
    for (int i = 0; i < l1; i++){
      seq[0].notes[i] = m1N[i];
      seq[0].times[i] = m1T[i];
      seq[0].lengths[i] = m1L[i];
    }
  //start seq 0
  myGain[0] = 1;
  envTimer[0].start(seq[0].getLengthOfStep(0));
  sampFreq[0] = voxFreq * seq[0].getSampleOffOfStep(0);
  samp[0].setFreq(sampFreq[0]*2);
  // masterGains[0] = 200;

  // create seq 1
  int m2N[] = {-3, -3, -3, -1, -3};
  int m2T[] = {4, 4, 4, 2, 2};
  int m2L[] = {2, 2, 2, 2, 2};
  int l2 = sizeof(m2N)/sizeof(int);
  seq[1].length = l2;
    for (int i = 0; i < l2; i++){
      seq[1].notes[i] = m2N[i];
      seq[1].times[i] = m2T[i];
      seq[1].lengths[i] = m2L[i];
    }
  //start seq 1
  myGain[1] = 1;
  envTimer[1].start(seq[1].getLengthOfStep(0));
  sampFreq[1] = voxFreq * seq[1].getSampleOffOfStep(0);
  samp[1].setFreq(sampFreq[1]);

  // create seq 2
  int m3N[] = {-5, -7, -5, -7, -5, -7, -5, -6, -7, -6, -7, -6, -7, -5};
  int m3T[] = {2, 2, 2, 2, 2, 2, 4, 2, 2, 2, 2, 2, 2, 4};
  int m3L[] = {2, 2, 2, 2, 2, 2, 4, 2, 2, 2, 2, 2, 2, 4};
  int l3 = sizeof(m3N)/sizeof(int);
  seq[2].length = l3;
    for (int i = 0; i < l3; i++){
      seq[2].notes[i] = m3N[i];
      seq[2].times[i] = m3T[i];
      seq[2].lengths[i] = m3L[i];
    }
  //start seq 2
  myGain[2] = 1;
  envTimer[2].start(seq[2].getLengthOfStep(0));
  sampFreq[2] = voxFreq * seq[2].getSampleOffOfStep(0);
  samp[2].setFreq(sampFreq[2]);

  // create seq 3
  int m4N[] = {11, 9, 7};
  int m4T[] = {1, 1, 1};
  int m4L[] = {1, 1, 1};
  int l4 = sizeof(m4N)/sizeof(int);
  seq[3].length = l4;
    for (int i = 0; i < l4; i++){
      seq[3].notes[i] = m4N[i];
      seq[3].times[i] = m4T[i];
      seq[3].lengths[i] = m4L[i];
    }
  //start seq 3
  myGain[3] = 1;
  envTimer[3].start(seq[3].getLengthOfStep(0));
  sampFreq[3] = voxFreq * seq[3].getSampleOffOfStep(0);
  samp[3].setFreq(sampFreq[3]);
  // masterGains[3] = 100;

  // create seq 4
  int m5N[] = {4, 4, 4, 4, 4, 4, 4, 4, 3, 3, 3, 3, 3, 3, 3, 3};
  int m5T[] = {2, 2, 2, 2, 2, 2, 2, 2, 2, 2, 2, 2, 2, 2, 2, 2};
  int m5L[] = {1, 1, 1, 1, 1, 1, 1, 1, 1, 1, 1, 1, 1, 1, 1, 1};
  int l5 = sizeof(m5N)/sizeof(int);
  seq[4].length = l5;
    for (int i = 0; i < l5; i++){
      seq[4].notes[i] = m5N[i];
      seq[4].times[i] = m5T[i];
      seq[4].lengths[i] = m5L[i];
    }
  //start seq 4
  myGain[4] = 1;
  envTimer[4].start(seq[4].getLengthOfStep(0));
  sampFreq[4] = voxFreq * seq[4].getSampleOffOfStep(0);
  samp[4].setFreq(sampFreq[4]);
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

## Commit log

2023-10-18 hardware+generative example
    [ESP32_AudioBoard_Rev2-B_Cu.gbr, ESP32_AudioBoard_Rev2-B_Mask.gbr, ESP32_AudioBoard_Rev2-B_Paste.gbr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]
2023-10-30 added sample examples
2023-10-30 added piano sample
2023-11-20 added filter example
2023-11-27 added granular example
    [ESP32_AudioBoard_Rev3-B_Cu.gbr, ESP32_AudioBoard_Rev3-B_Mask.gbr, ESP32_AudioBoard_Rev3-B_Paste.gbr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]
2024-02-03 meap update
    [MEAP_Rev3b-B_Cu.gbr, MEAP_Rev3b-B_Mask.gbr, MEAP_Rev3b-B_Paste.gbr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]
2024-03-06 lots of updates eek
    [MEAP_Rev3b.kicad_pcb]
2024-04-22 added meap library
    [MEAP_Rev3b-B_Cu.gbr, MEAP_Rev3b-B_Mask.gbr, MEAP_Rev3b-B_Paste.gbr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]
2024-04-22 updated documentation
    [MEAP_Rev3b.kicad_sch]
2024-06-18 lots of stuff
    [MEAP_Rev3c copy.csv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]
2024-08-01 library updates for meap rev3
    [MEAP_REV4_BOM.csv, MEAP_REV4_BOM_LCSC.csv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]
2024-08-14 removed my extra code, updated library to support MEAP Rev4
    [MEAP_REV4_BOM.csv, MEAP_REV4b_BOM_LCSC.csv, MEAP_Rev4.kicad_pcb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]
2024-08-14 restructured directories
    [meap.csv]
2024-09-06 lots of changes eek
    [meap.csv]
2024-09-16 updated examples and tutorials
    [ESP32_AudioBoard_TouchPanel_Rev2.kicad_pcb, MEAP_REV4_BOMfff.csv, MEAP_REV4b_BOM.csv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]
2024-09-23 new wavetables, code cleanup, more examples and tutorials
    [MEAP_Rev4b.kicad_sch]
2024-11-21 added mSample reverse, etc
    [Meap_classes.h]
2024-12-03 updated board partition
    [meap.csv]
2025-01-24 hardware updates
    [MEAP_Rev4c.kicad_pcb, MEAP_Rev4c.kicad_sch, MEAP_Rev4c.sch]
2025-02-20 big update
    [MEAP_REV4C_BOM.csv, MEAP_REV4C_BOM_FILLED.csv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]
2025-07-16 removed hardware files
    [ESP32_AudioBoard_Rev2-B_Cu.gbr, ESP32_AudioBoard_Rev2-B_Mask.gbr, ESP32_AudioBoard_Rev2-B_Paste.gbr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]
2025-07-16 rearranged filestructure
    [meap.csv]
2025-09-14 re-added meap board definitions
2025-10-06 QOL improvements to mOscil and mSample, mStringSynth bug fixed
    [Meap_classes.h]
2026-06-16 instrument improvements, new wavetables/windows, moved to new esp32-arduino touch api as required
